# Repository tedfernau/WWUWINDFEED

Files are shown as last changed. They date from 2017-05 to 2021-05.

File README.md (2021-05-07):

# WWU WIND FEED

WWU Wind Feed was my 2017 senior project in electrical engineering. WWU Wind Feed is a microcontroller device that serves a web page with the current wind speed at Western Washington University's Lakewood Boathouse in Bellingham WA, USA.

The project was to develop an embedded system from concept to prototype, designing and building custom hardware and firmware.

https://user-images.githubusercontent.com/7742005/117382242-ee376c80-ae92-11eb-8817-17ec5c702b5a.mp4

The demonstration video is also on [youtube](https://www.youtube.com/watch?v=sEgjqADhZPg)

## Conceptual Design

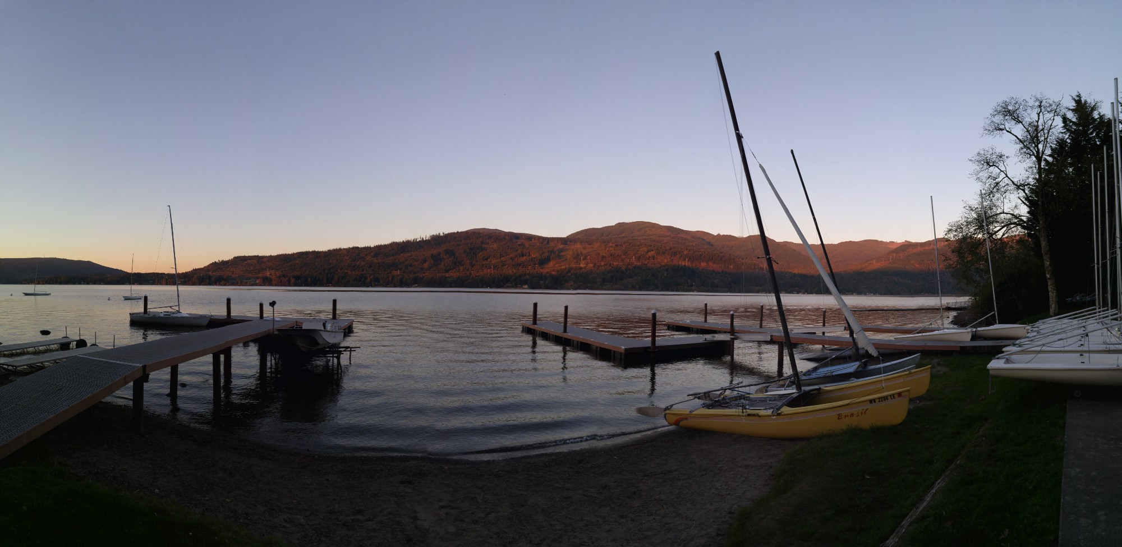
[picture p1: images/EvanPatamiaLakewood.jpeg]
Evan Patamia Lakewood photo
*Boathouse at WWU*

Western Washington University has a great boathouse on Lake Whatcom. Students rent sailboats, windsurf boards and various other watercraft and take classes and lessons. I learned to sail in a class at Lakewood, and later worked there teaching sailing lessons.

To have a good day of sailing you need wind. When you want to go sailing, you should check the wind conditions. A quick google search will give you decent wind data, but it is better to have localized data for the specific water you will be boating on. WWU Wind feed aims to provide this information. 

The ideal solution would provide all the data anyone needs to decide whether to visit Lakewood: wind on the water, and also temperature and weather conditions, a weather forecast, or maybe a picture, perhaps even boat or parking availability. The data would be made available as conveniently as possible to interested parties. This may be a social media post for subscribers(a great job for a Twitter bot) or a widget on the Lakewood webpage. This is a weather station and inventory system with serious web capability! Compromises were made... to provide only wind data and to serve a simple webpage.

More compromises. We sail on the middle of the lake, this is the wind we want to measure. This requires a buoy, solar panel, a battery, long range wireless communication to an internet gateway (cellular or perhaps LORA), weather proofing and permission for installing such a buoy. For achievability and cost savings, I decided the device will be at the boathouse, plugged into the wall, connected to the Lakewood WiFi.

Below I dumped documents for a technical audience to quickly evaluate this project followed by a brief conclusion. Feel free to reach out to me for more information.

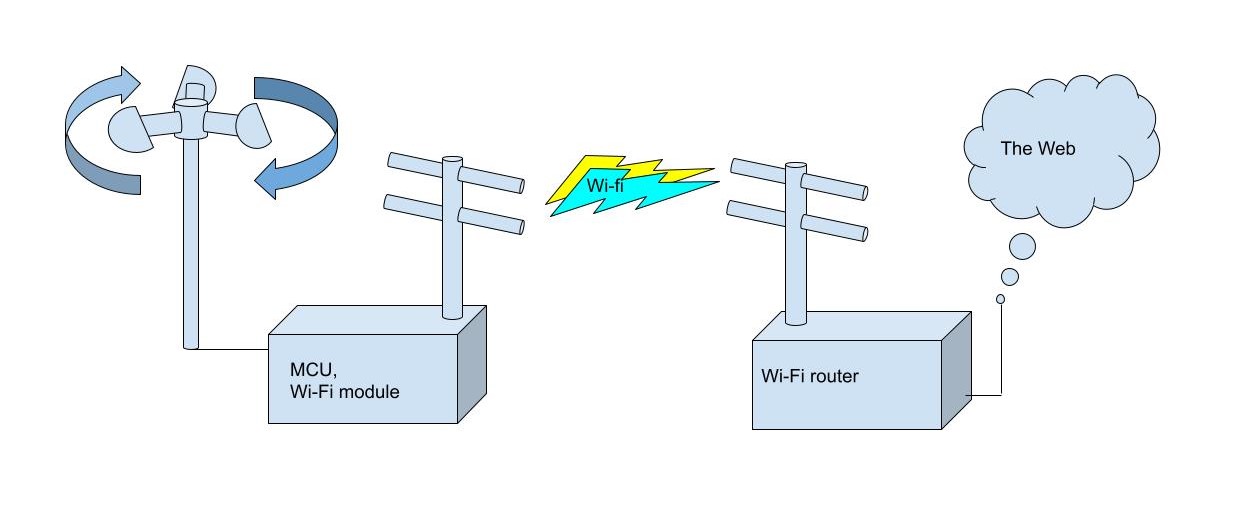
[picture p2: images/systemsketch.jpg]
System concept
*System Sketch*
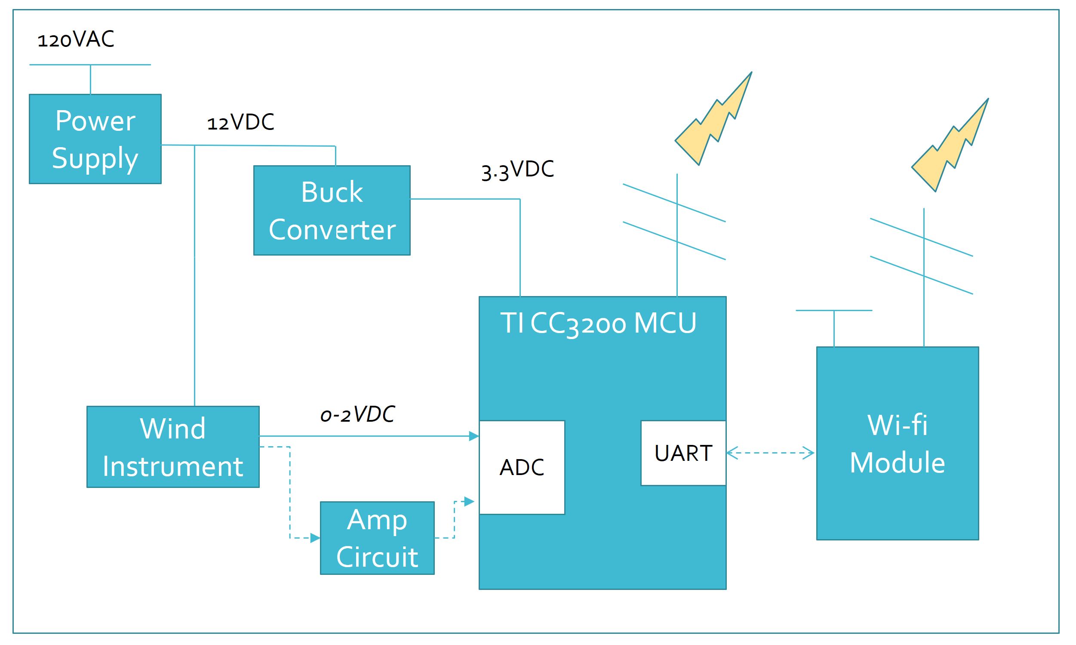
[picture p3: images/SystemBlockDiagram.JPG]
System Block Diagram
*System Block Diagram*

## [Hardware](https://github.com/tedfernau/WWUWINDFEED/tree/master/hardware)

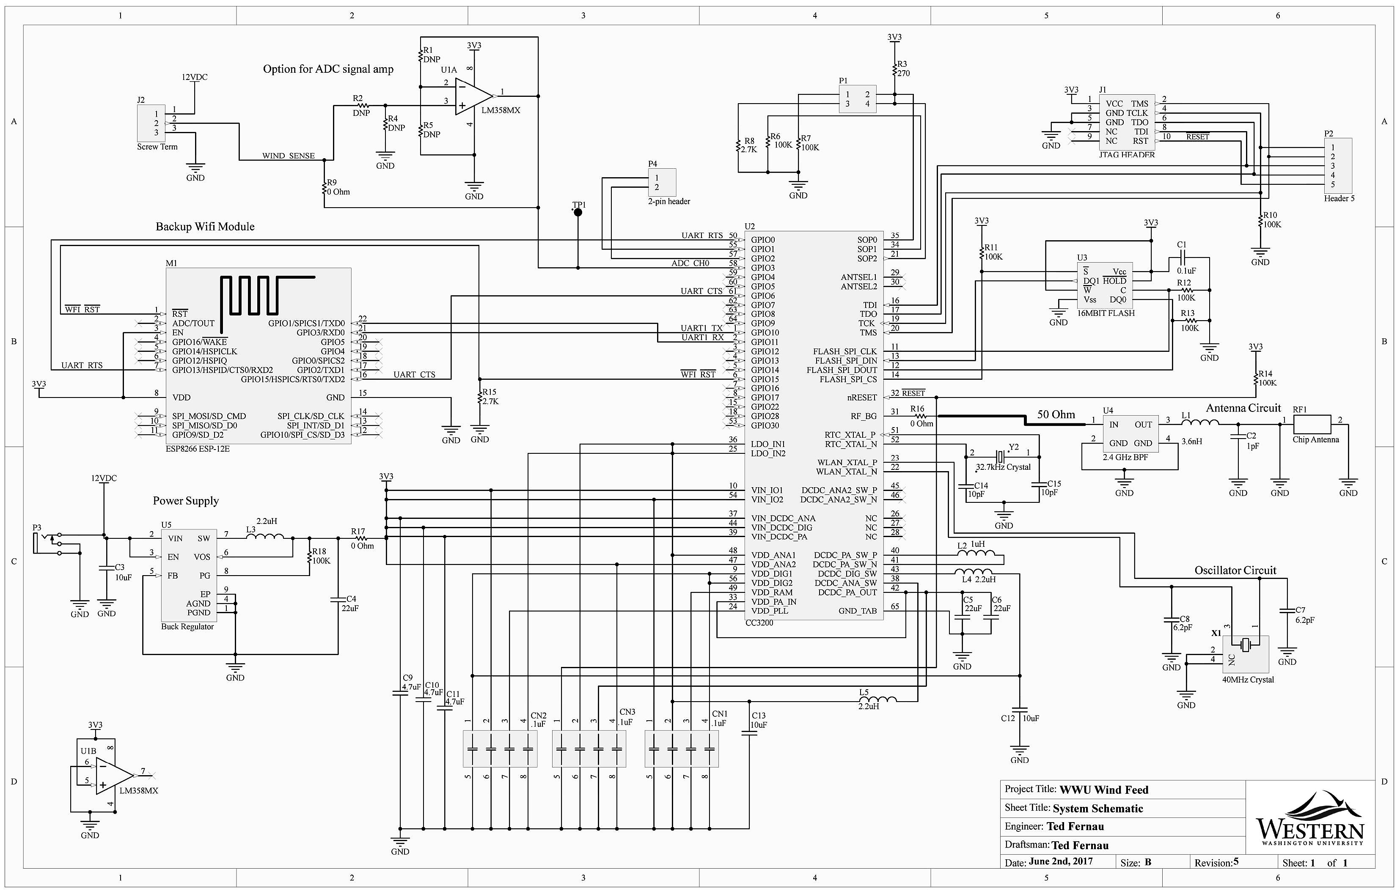
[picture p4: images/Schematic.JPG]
Schematic
*Schematic*
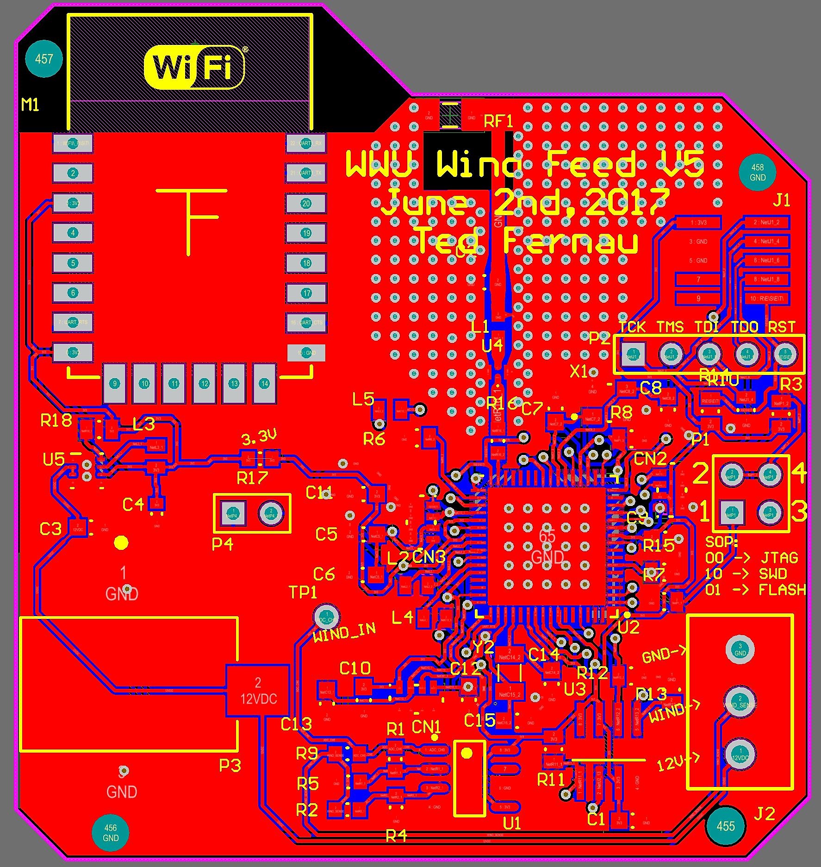
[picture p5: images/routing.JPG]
Composite Layout and Routing
*PCB Layout*
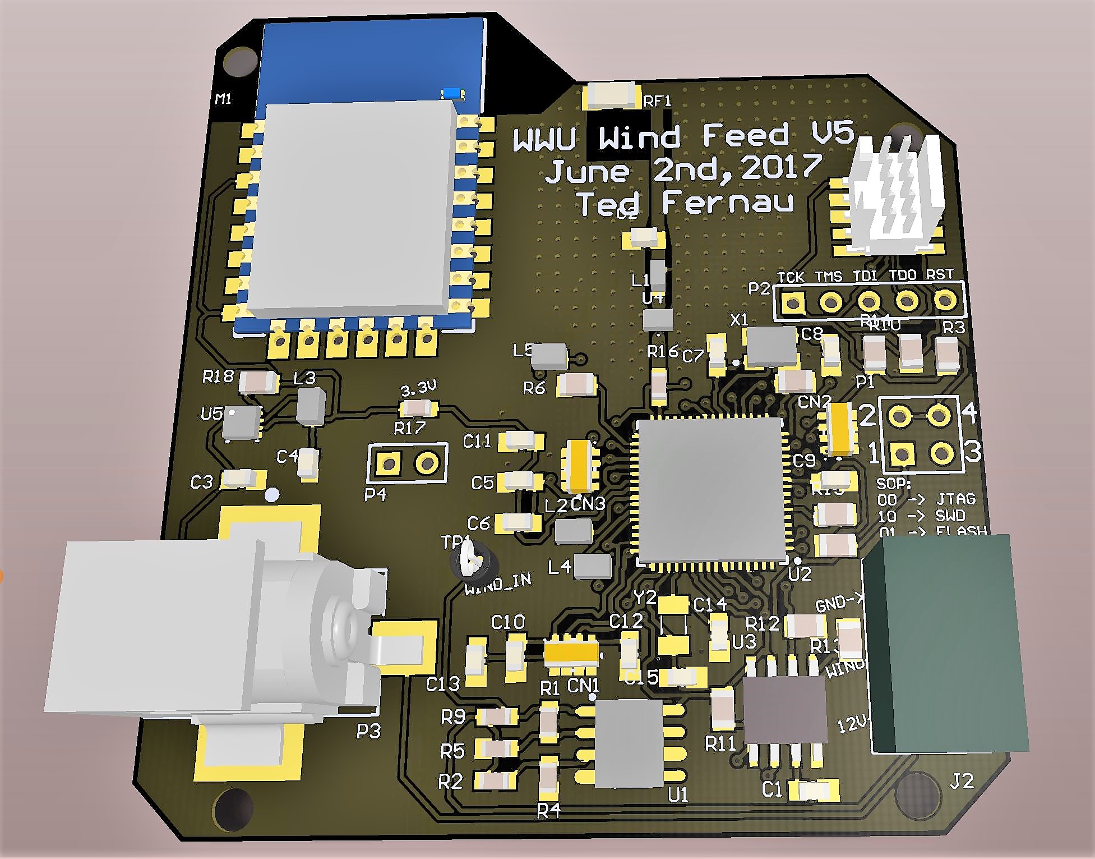
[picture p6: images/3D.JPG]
3D rendering
*Rendering of PCB*
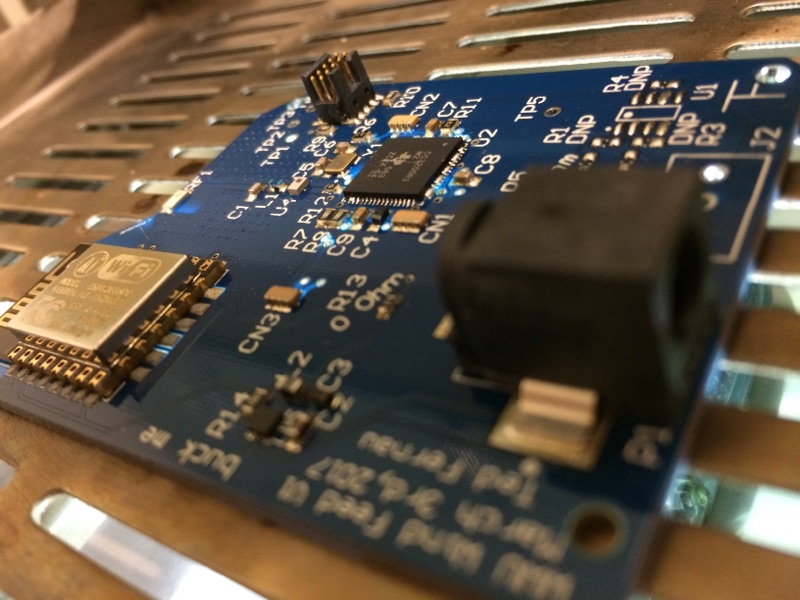
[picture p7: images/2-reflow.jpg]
Reflow
*PCB Assembly - Reflow*

## [Firmware](https://github.com/tedfernau/WWUWINDFEED/tree/master/firmware)

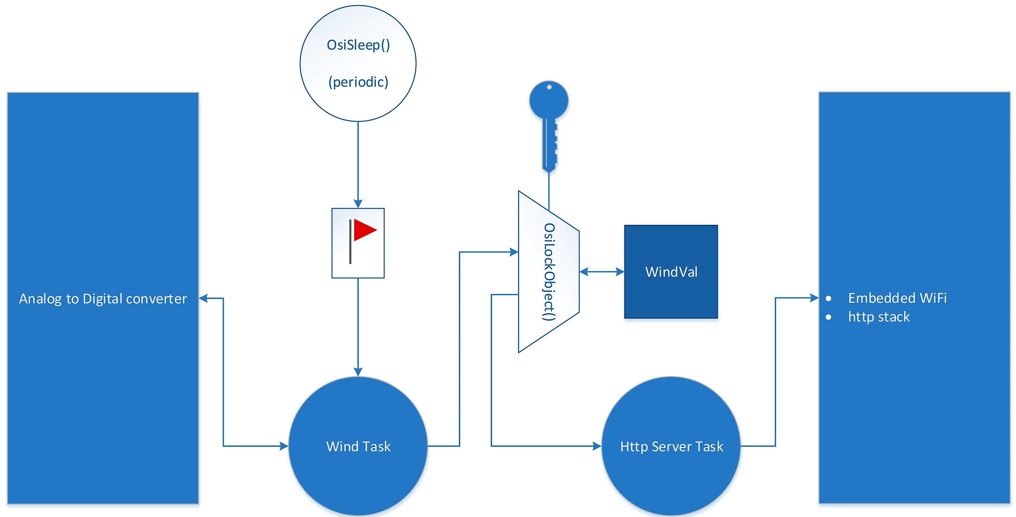
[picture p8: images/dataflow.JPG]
dataflow
*Dataflow Diagram*
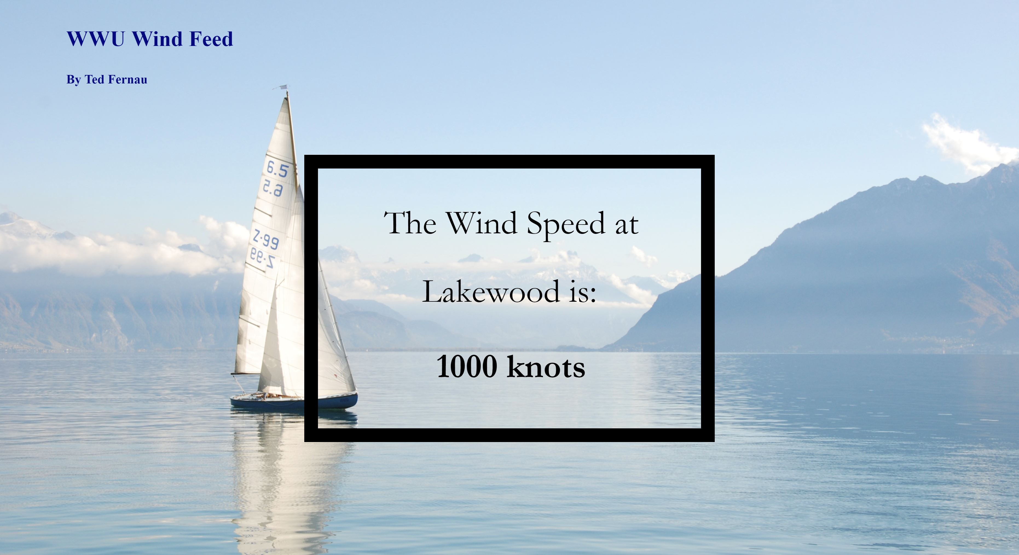
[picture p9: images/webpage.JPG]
webpage
*Webpage Design*

## Thoughts

This project was a great first dive into product design, mixed signal electronics design, PCB design, PCB assembly, debugging and rework, firmware development in C, and project management. The experience revealed deficits in my skills, knowledge, and personality. These revelations have been useful.

If I were going to pick this project up again, I would not make all the compromises I mentioned above. The device would run off of solar, and would not use WiFi for accessing the network. I am not sure a buoy is worth the hassle, but perhaps the device could be attached to a dock or piling and still give useful data(needs study). I would likely try to provide a picture of water conditions at least, and would look into providing the data more places on the web. 

Thank you for stopping by. Feel free to contact me, my info is on my github profile.

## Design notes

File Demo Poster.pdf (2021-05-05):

# WWU WIND FEED

# A custom IoT weather station. Designed to

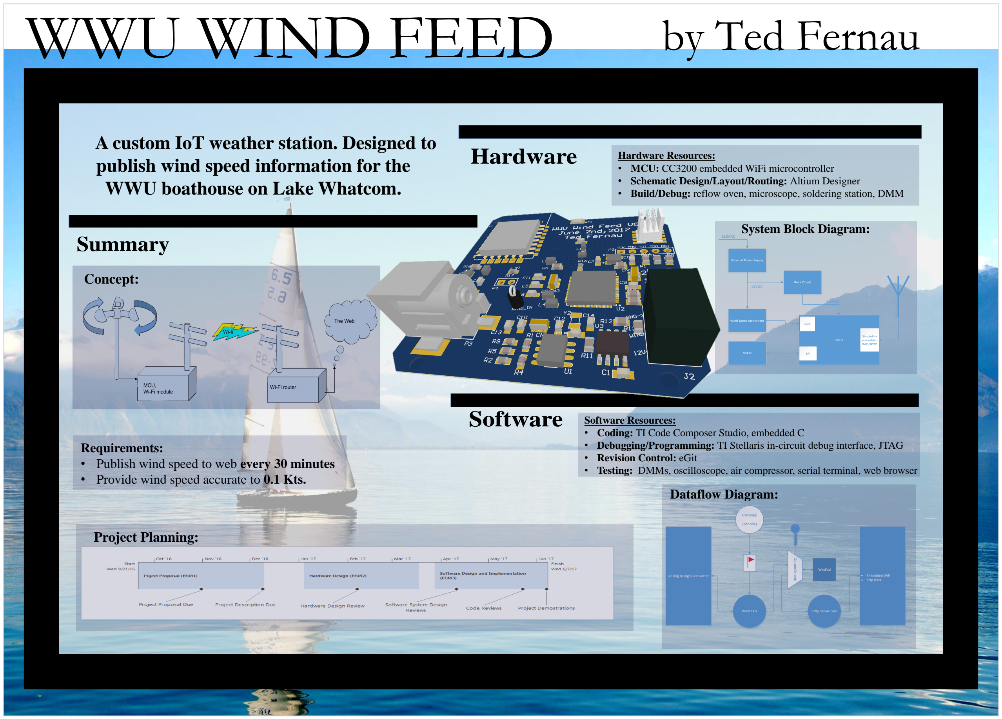
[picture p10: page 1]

# publish wind speed information for the

WWU boathouse on Lake Whatcom.

# Hardware Summary

### Requirements:

### - Publish wind speed to web every 30 minutes

- Provide wind speed accurate to 0.1 Kts.

## Project Planning:

# by Ted Fernau

External Power Supply

Wind Speed Instrument

Buck Circuit

SRAM

MCU

ADC

Simplelink
embedded
WiFi/HTTP

SPI

120VAC

12VDC

## 3.3VDC Concept:

Hardware Resources:
- MCU: CC3200 embedded WiFi microcontroller
- Schematic Design/Layout/Routing: Altium Designer
- Build/Debug: reflow oven, microscope, soldering station, DMM

Software Resources:
- Coding: TI Code Composer Studio, embedded C
- Debugging/Programming: TI Stellaris in-circuit debug interface, JTAG
- Revision Control: eGit
- Testing: DMMs, oscilloscope, air compressor, serial terminal, web browser

### Dataflow Diagram: System Block Diagram: Software

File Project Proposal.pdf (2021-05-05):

## EE 491 Senior Project Proposal WWU Wind Feed

### Ted Fernau

Summary

The WWU Wind Feed is a tool to deliver wind information to users of the WWU boathouse on Lake Whatcom. The system will collect wind speed (and possibly other) data and upload it to the Internet at regular intervals. The device utilizes an off the shelf marine anemometer, and does information processing and communication with an embedded microcontroller and a Wifi module. The system will be powered by the grid.

### 1 Detailed Description

The goal of this project is to provide wind speed data for the users of the WWU boathouse on Lake Whatcom. The wind conditions on the lake in front of the facility are unpredictable and are not accurately represented by the weather forecast for Bellingham. For this reason members of the WWU wind sport community frequently call Lakewood for a wind update. I propose a device to measure wind speed periodically and publish the data online for user consumption. Providing current wind conditions makes it easier for users to decide when to go boating. This device utilizes the fact that most WWU students and alumni have smart phones, and can access the web conveniently.

Wind speed is the focus of this project because this is vital information for those who participate in wind sports. Wind sports equipment represents the bulk of the available rentals at the WWU boathouse. Other local information is important for the users of the WWU boathouse such as air temperature, water temperature, hours of operation, wind direction, etc. This other data is reported by the Bellingham weather forecast.

The goal described above leads to the following product features, listed in order of priority:

Make current wind speed available to WWU boaters. This is the key feature of the project. This feature is necessary due to the reasons described above, that wind speed is not accurately represented by weather reports, wind speed is the most important information for those who enjoy wind sports, and wind sports represent most of the resources available to the WWU community.

Provide historical wind data to indicate trends. Besides the current wind speed, an important determinant of sailing conditions is the wind speed trend. This allows users to determine whether the wind speed is increasing or decreasing, and thus better choose when to sail. Ideally, publishing the information would include a graphical output, providing context for the current wind speed.

Publish wind data in the optimal format for user consumption. Some formats are more convenient for users than others. The easiest way to accomplish the goal of making information available to all is to publish data on a web page. Users can be assumed to have internet access. Mobile internet access is also ubiquitous and represents an important and growing proportion of information services. In addition to a simple web page, social media may be an efficient way to deliver to those interested. It has been proposed that using the Lakewood Twitter feed may increase visibility.

Provide other relevant data besides such as wind direction, temperature, and barometric pressure. There is other information that could be useful to users. It would be ideal to publish as much relevant data as possible, in order to provide the most benefit to the most people. Some possible additions are wind direction, temperature, and barometric pressure data.

### 2 Constraints and Standards

There is limited space available at the Lakewood facility, and still less space that is exposed to wind conditions similar to those at the middle of the lake. The space occupied must be suitable to accomplishing the goal of the project, while being suitable to Lakewood users and management.

In order to meet the goal, and provide for the features listed above and the benefits below, the product must be reliable. The device must withstand outdoor conditions with little or no maintenance over the lifecycle.

The cost must be on par with other low end solutions on the market, which is roughly under $200. This is a fixed device that would be installed for long term use. This is also a custom solution, which allows for some deviation in price for the purpose of reliability and key features. The budget for developing a prototype is subject to the limitations of the personal finance of the creator.

The product must operate without affecting boathouse operations. This is not a project Lakewood management is seeking out, thus there is little accommodation for any imposition on the facility and operations, thus product must be retrofitted to the boathouse as it presently exists. This means the product must communicate with the existing network using standard protocols.

The product must be designed, with a working prototype, by early June. This limits the likelihood of added features. The features will be developed in order of importance. There will be no added features until the initial goal is satisfied, and it is cost and time effective to add them.

### 3 Benefits

This product is meant to demonstrate a possible application for the 'Internet of Things' (IoT), and represents a template for a broad range of possible products. In the process of developing this solution I will become familiar with the relevant issues for IoT design. The product is also an exploration of the so-called information economy. One of the largest roles for technology in today’s world is to provide relevant information to economic participants in order to reduce transaction costs, thus leading to more efficient market outcomes. I see the end point of this progression as a more informed society that is better able to understand and react to our changing world.

This product benefits the user by providing the necessary information to utilize a small segment of the WWU recreational resources. If the solution is properly implemented, it will make the Lakewood Boathouse a more efficient organization by reducing the cost associated with providing redundant information.

Most of the solutions that currently exist come in two forms: boat mounted instrument systems that provide wind data for a vessel, and remote weather stations for home or commercial use. The products for boats differ from my design since they are not generally broadcast oriented, instead displaying information to the vessel crew to be used in the moment.

Remote weather stations are more similar to this design, since they monitor conditions at a remote location and display at a base station. These products come with various features, some that are accessible with a smart phone or tablet. These are largely integrated systems that vary largely in features and cost. My solution is a scaled back version of a remote weather station, with the focus on making the data ubiquitous by putting in on the web. Another difference is this product is meant to represent many one off designs that could be fitted to any application.

The broader benefits of this product is reduced cost of Lakewood usage for the users, WWU, and society. The cost of usage is saving a phone call or a trip out to the Boathouse. The benefit to Lakewood management is a decrease in inquiries about wind conditions, thus freeing resources for more efficient operation. Society benefits from the decreased energy consumption from fewer wasted trips.

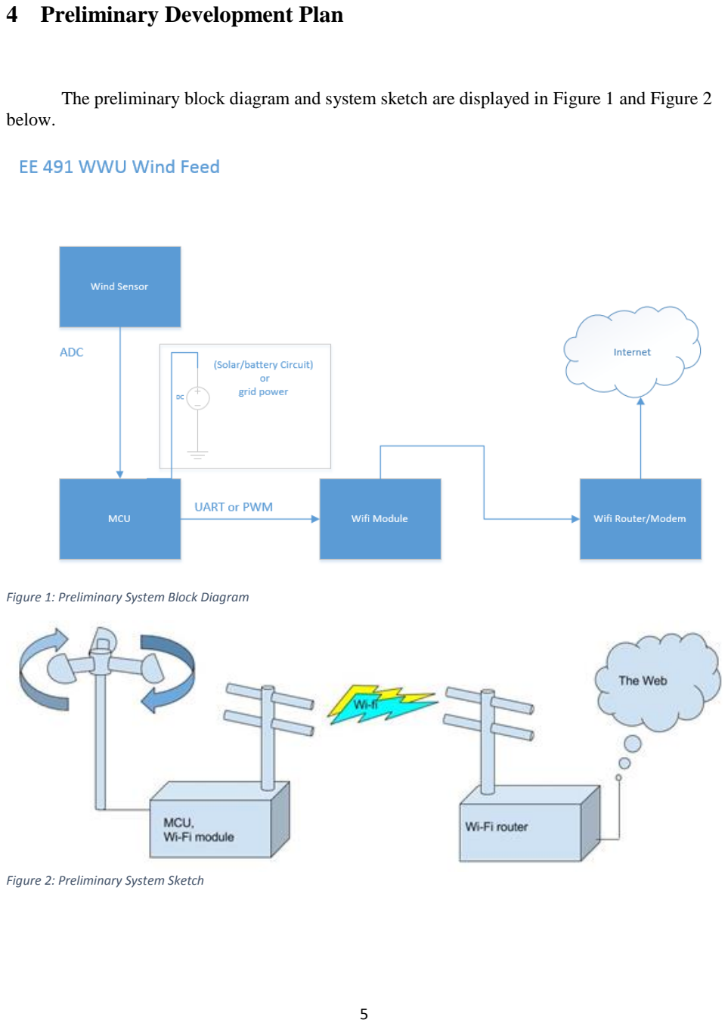
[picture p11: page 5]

### 4 Preliminary Development Plan

The preliminary block diagram and system sketch are displayed in Figure 1 and Figure 2 below.

Figure 1: Preliminary System Block Diagram

Figure 2: Preliminary System Sketch

In order to design and implement this product, I will first need to answer a couple initial questions: Where is the optimal location to accurately monitor wind speed on the Lakewood campus? In order to answer these questions, I will consult with Lakewood management and
WWU EE faculty for relevant constraints and guidance.

Once I have decided these details, the next step is to source parts that will be optimum for a prototype. I plan on purchasing the anemometer early to build a rough prototype of the sensor circuit, and to optimize the instrument location. This sourcing of parts will be done online, or possibly at local marine supply stores.

I will be designing an IC for the prototyping and implementation, so I will next decide which micro controller will be optimum for my design, as well as necessary peripherals including the Wi-Fi module. This will be done by finding the relevant constraints, and searching online for components that achieve the maximum required performance, without extra cost or complexity.

Once the hardware design is complete, I will move to software design and implementation. For this I will utilize the resources that exist in the WWU EE labs.

Once the design is complete, I will move to implementing a prototype using the WWU EE lab resources as much as possible.

Depending on the quality of the prototype, I will work to implement a version of the system at the Boathouse. I would like to have a prototype to demonstrate in the lab, as well as the stream of actual weather data from the lake.

### 5 Bibliography

Possible parts:

Wind Sensor:

http://www.ebay.com/itm/Climatronics-Wind-Speed-Sensor-100075-/331589368095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

http://www.ebay.com/itm/Wind-Speed-Sensor-Anemometer-Three-Cups-Aluminium-Alloyed-Voltage-Output-0-5V-
/322206596553?hash=item4b05027dc9:g:FCsAAOSweXhXmFCu (http://www.ebay.com/itm/Wind-Speed-Sensor-Anemometer-Three-Cups-Aluminium-Alloyed-Voltage-Output-0-5V-/322206596553)

https://www.adafruit.com/product/1733

Wi-Fi Module:

http://gridconnect.com/tiny-wifi-module-802-11-b-g-n-industrial-grade-temperature.html

Relevant Academic Papers:

M. Popa and C. Iapa, "Embedded weather station with remote wireless control," Telecommunications Forum (TELFOR), 2011 19th, Belgrade, 2011, pp. 297-300.

URL: http://ieeexplore.ieee.org/stamp/stamp.jsp?tp=&arnumber=6143549&isnumber=6143488

A. Shaout, Yulong Li, M. Zhou and S. Awad, "Low cost embedded weather station with intelligent system," Computer Engineering Conference (ICENCO), 2014 10th International, Giza, 2014, pp. 100-106.

URL: http://ieeexplore.ieee.org/stamp/stamp.jsp?tp=&arnumber=7050439&isnumber=7050418

B. C. Mishra, A. S. Panda, N. K. Rout and S. K. Mohapatra, "A Novel Efficient Design of Intelligent Street Lighting Monitoring System Using ZigBee Network of Devices and Sensors on Embedded Internet Technology," 2015 International Conference on Information Technology (ICIT), Bhubaneswar, 2015, pp. 200-205.

URL: http://ieeexplore.ieee.org/stamp/stamp.jsp?tp=&arnumber=7437615&isnumber=7437547

Xiaoneng Gao and Pengtong Fan, "Internet access technology based on the embedded devices," Multimedia Technology (ICMT), 2011 International Conference on, Hangzhou, 2011, pp. 391-394.
URL: http://ieeexplore.ieee.org/stamp/stamp.jsp?tp=&arnumber=6001932&isnumber=6001647

Relevant Datasheets:

http://www.climatronics.com/pdf_pn/Wind_Speed_Direction/100075,100076,101994.pdf

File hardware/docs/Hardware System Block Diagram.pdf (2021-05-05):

### 120VAC

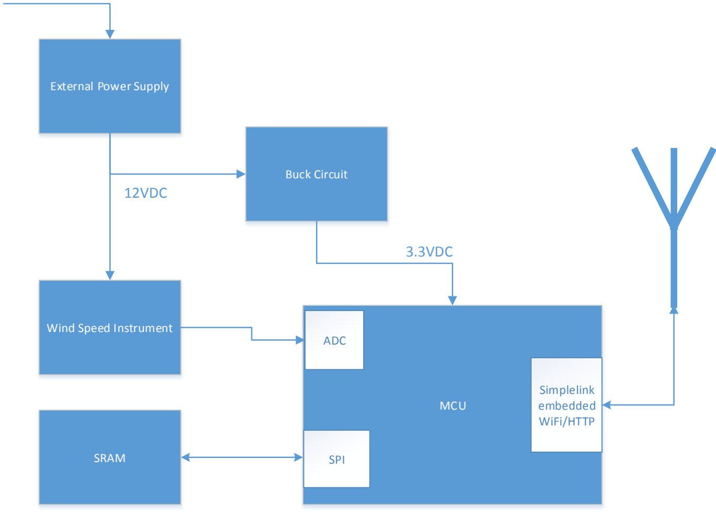
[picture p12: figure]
External Power Supply; Wind Speed Instrument; Buck Circuit; SRAM; MCU; ADC; Simplelink embedded WiFi/HTTP; SPI; 12VDC; 3.3VDC

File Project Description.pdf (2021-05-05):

## EE 491 Senior Project Description WWU Wind Feed

## Ted Fernau

### Summary

The WWU Wind Feed is a tool to deliver wind information to users of the WWU boathouse on Lake Whatcom. The system will collect wind speed (and possibly other) data and upload it to the Internet at regular intervals. The device utilizes an off the shelf marine anemometer, and does information processing and communication with an embedded microcontroller and a Wi-Fi module. The system will be powered by the grid.

## 1 Project Requirements

- The device must publish the current wind speed for Lake Whatcom’s third basin on a webpage that is easily available for PC and smartphone access.
- The wind feed website will be hosted on the device.
- Online information must be updated every 30 minutes.
- Published wind speed information must be accurate to within 1 knot with a resolution of 0.5 knots.
- The device must operate to specifications in wind speeds from 1 knot to 60 knots.
- The device must operate in temperatures from -18 to 40 degrees Celsius.
- All outdoor components, the wind speed instrument and cable, must withstand year round weather conditions.
- The device must cost less than 200USD to implement from the supply side.
- The device must interface with the local internet router via Wi-Fi protocols IEEE 802.11 b/g/n, and must be able to meet security constraints for network access.
- The device must be powered by a standard 120VAC outlet and draw less than a typical Wi-Fi router, about 50 mA (for 6Watts).
- The device must be the roughly the size of a standard internet router/modem, roughly 4 inches by 6 inches by 1 inch.

## 2 System Design Formulation and Specifications

The product collects weather data via an anemometer instrument. The instrument is a transducer from wind speed to a linear voltage output from 0.4 to 2V DC. The anemometer requires a 12VDC power supply. This signal is sampled by the ADC of the microcontroller, and the wind speed is calculated based on the input signal. Wind speed data is passed to the Wi-Fi module using UART. The Wi-Fi module has integrated TCP/IP protocols to communicate with the local Wi-Fi network. The device accesses the network in order to serve the webpage which displays current wind conditions. This website is hosted by the device.

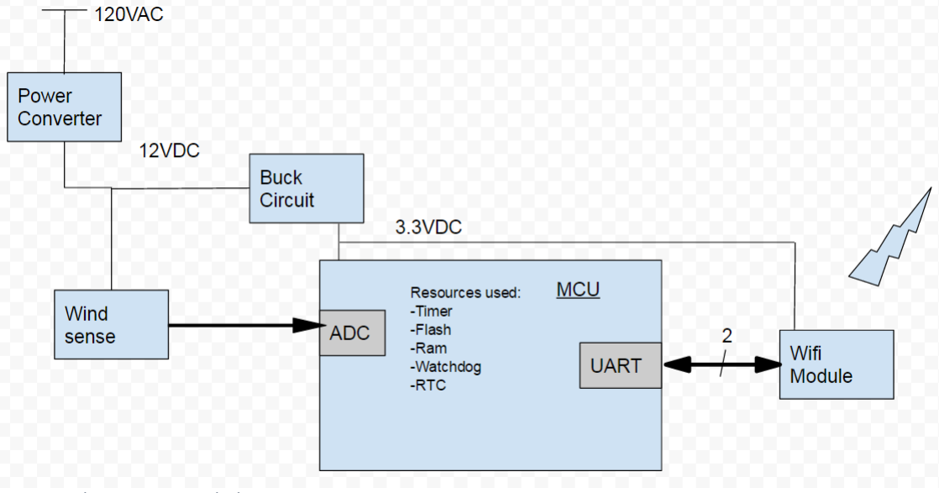
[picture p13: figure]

Figure 1: Preliminary System Block Diagram

a. Hardware

Microcontroller Specs: For this project I require at least 38kB ROM, 0.1 kB RAM, an ADC range of 193 levels, so 9 bit resolution. The project requires an MCU with UART capabilities. The MCU listed in appendix A meets these requirements, but has some superfluous features: 64kB ROM, 16kB RAM, UART, 16 and 24 bit ADCs.

Resources: The MCU resources I will use for this project are the ADC to sample the wind speed instruments voltage output, UART for communication between the MCU and the Wi-Fi module, a timer for the periodic updating of wind information, the watchdog timer, since the device will run continuously, to reset the system in the case of an error, and the RTC if I implement a timestamp publication.

Other components: the Wi-Fi Module must operate at the same supply voltage as the MCU, in this case 3.3V. The Wi-Fi module must also either be a Surface mount component or have a form factor small enough to fit in the form described above. The Wi-Fi module must communicate using the IEEE 802.11 b/g/n protocol for compatibility with the in-place Wi-Fi system. The wind speed transducer must be weatherproof for continued outdoor operation, and must produce a voltage signal between 0 and 3.3V for use with the MCU ADC. Ideally the transducer would be self-powered, but the self-powered instruments are proprietary and expensive. The sensors I considered had a minimum supply voltage of 12VDC, so I will supply 12V to the sensor.

Power Supply Specs: The 120VAC to 12VDC must supply 500mA. The system is estimated to draw about 80mA from the 120 to 12 converter, I am using a very conservative margin of error. The 12VDC to 3.3VDC must supply a minimum of 200mA, but again I will use 500mA to ensure performance.

PCB size Requirements: The device as a whole must resemble a Wi-Fi router in form. This means the device must be roughly 4 inches wide by 6 inches long by 1 inch tall. This leaves room for a 3.5 inch by 5.5 inch PCB if necessary. I used these dimensions in my parts list, but I will attempt to use a smaller PCB to save cost.

b. Software

Programming languages: I will program the board in Kinetis Design Studio, which uses
C. For the webpage I will use HTML.

Real time kernel Type: uC/OS by Micrium is the kernel I have experience with, so I will most likely use it for software multitasking.

Major algorithms: The Wi-Fi module has integrated TCP/IP, I will be coding using HTTP to serve the webpage.

## 3 Development Plan

a. Prioritized list of device features Primary
1. Make current wind speed available to WWU boaters.
Secondary
2. Provide timestamp with wind speed, display historical wind data.
3. Publish wind data in the optimal format for user consumption (i.e. | social via social media).

Table 1: Prioritized list of features

b. Description of project development tasks and sequence
Winter Quarter 2017 - Hardware Design
Week | Dates | Tasks
1 | Jan 4-6 | Verify hardware block diagram as optimum design
2 | Jan 9-13 | Order parts essential to prototyping such as the wind sensor, simulate circuitry to verify design integrity.
3 | Jan 16-20 | Begin characterizing wind sensor output, Learn Altium tool
4 | Jan 23-27 | Buy and test as many components as possible.
5 | Jan 30-Feb 3 | Develop prototype of major device functions for onsite testing
6 | Feb 6-10 | Finalize circuit layout, produce complete schematic of system Hardware Design Reviews Feb 7th
7 | Feb 13-17 | Review schematic for PCB fabrication
8 | Feb 20-24 | Order PCB
9 | Feb 27-March 3 | Breadboard whatever possible while waiting for PCB
10 | March 6-10 | Assemble hardware for testing.
11 | March 13-17 | Catch up
Spring Quarter 2017 - Software Design
Week | Dates | Tasks
1 | March 28-31 | Formulate top level block diagram
2 | April 3-7 | Research web servers, TCP/IP, static websites, possible publishing media PCB Fully Assembled and Tested April 4th
3 | April 10-14 | Formulate detailed block diagrams of modules Software System Design Reviews April 11th
4 | April 17-21 | Develop basic prototype for testing
5 | April 24-28 | Catch up
6 | May 1-5 | Catch up
7 | May 8-12 | Implementation
8 | May 15-19 | Implementation
9 | May 22-26 | Implementation and prepare presentation Code Reviews May 23
10 | May 29- June 2 | Catch up
11 | June 5-9 | Project Demonstrations June 7th (subject to changes)

Table 2: Project development plan c. Description of development hardware and software including source

Software: I will be using Kinetis Design Studio to program the MCU, Altium for PCB layout, Multisim for circuit simulation. I will utilize online weather forecasts in order to verify the accuracy of the device.

Hardware: I will need to find a wind speed meter to fine tune my accuracy and to verify the required resolution. I will utilize oscilloscopes, power supplies, multimeters, and fabrication supplies to build and test hardware and software systems. For prototyping, I will use as many components from the EE stock room as possible to avoid lead times and cost.

d. Prototype description

The prototype demonstration will occur in the EE labs. I will have a wind speed instrument set up with the online publishing occurring much faster than otherwise specified, likely every 30 seconds or so. A person will move the wind speed sensor, perhaps by blowing/a fan/ hand manipulation and watch as the webpage updates. Ideally I would have the final device in place at the boathouse for a real world demonstration, but I do not want to pay for two prototypes unless necessary.

## 4 User Interface Requirements

The user interface for this project takes the form of a web page. This web page should be viewable by users on a PC or smart phone. The UI is very simple since it only publishes data. There is no user control, only observation.

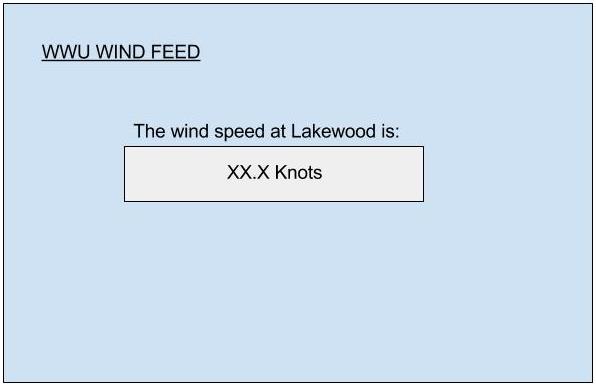
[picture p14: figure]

Figure 2: Sketch of website user interface

## Appendix A – Preliminary Parts List

Part number | Quantity | Description | Cost(USD) | Lead time | Current consumption (mA)
Power
dissipation
(W)

URL

120VAC to 12VDC converter
TOL-09442 | 1 | Wall Adapter Power
Supply - 12VDC
600mA
5.95 | 1-2 weeks | 600mA | Assume
| | | 85% efficiency

https://www.sparkfun.com/products/9 442

Supplied by 120VAC to 12VDC converter
1733 | 1 | Anemometer Wind
Speed Sensor
w/Analog Voltage
Output
44.95 each | 1-2 weeks | 4-20 | 0.240 | https://www.adafruit.com/product/173
| | | | 3

### 12 to 3.3VDC converter

TPS62172DSG R | 1 | Buck Switching Regulator IC Positive Fixed 3.3V 1 Output 500mA 8-WFDFN Exposed Pad | 1.56 | 1-2 weeks | 526 | 6.312 | http://www.digikey.com/product-detail/en/texas-instruments/TPS62172DSGR/296-39449-1-ND/5143397
PJ-035-SMT-TR | 1 | DC barrel Jack | 1.34 | 1-2 weeks | N/A | N/A | http://www.digikey.com/product-detail/en/cui-inc/PJ-035-SMT-TR/CP-035PJCT-ND/1530992-ltTikw66e-BR-Y4oCKYaRoCikTw_wcB
80-T322C106K15 AT | 1 | Tantalum Capacitors -Solid Leaded 15V 10uF 10% | 1.96 | 1-2 weeks | N/A | 0.1 | http://www.mouser.com/ProductDetail/Kemet/T322C106K015AT/?qs=sGA EpiMZZMsh%252b1woXyUXj2MEb xGkEkhEwwHS%2fNM7xfA%3d
TLCU226M00 6XTA | 1 | Tantalum Capacitors - Solid SMD 6.3volts 22uF 20% | 2.81 | 1-2 weeks | 54 (@100kHz) | 0.178 | http://www.mouser.com/ProductDetail/AVX/TLCU226M006XTA/?qs=sG AEpiMZZMsh%252b1woXyUXj2BG 3d9BWqHTUCbLPZ3%2fYBY%3d
TFM201610A LM-2R2MTAA | 1 | Fixed Inductors 2.2uH 146mohms 2.1A Thin Film Metal | 0.69 | 1-2 weeks | 2100 | 6.9 | http://www.mouser.com/ProductDetail/TDK/TFM201610ALM-2R2MTAA/?qs=sGAEpiMZZMukHu %252bjC5l7YXWyGFGQPUf1VJZQ eiZdbQI%3d
ESR10EZPJ1 04 | 1 | Thick Film Resistors - SMD 0805 100Kohm 5% Anti Surge AEC-Q200 | 0.10 | 1-2 weeks | N/A | N/A | http://www.mouser.com/ProductDetail/ROHM-Semiconductor/ESR10EZPJ104/?qs=s GAEpiMZZMtlubZbdhIBIGrVcSH3v ih4Eh1TPh5CImY%3d

Supplied by 12 to 3.3VDC converter
MOD-WIFI-ESP8266-DEV (or CC3100MOD) | 1 | Wi-Fi / 802.11 Development Tools WIFI MODULE ESP8266 DEV BOARD | 6.91 | 3 weeks | 170 | 0.561 | http://www.mouser.com/search/ProductDetail.aspx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
MKM14Z64A CHH5 | 1 | ARM Microcontrollers - MCU Kinetis M 32-bit MCU, ARM Cortex-M0+ core, 64KB Flash, 50MHz, MAPBGA 44 | 3.12 | 8 weeks | 11.5 run mode, with peripherals | 0.038 | http://www.mouser.com/ProductDetail/NXP-Freescale/MKM14Z64ACHH5/?qs=d Tl%2FGK1lAHKE9y6dPqmtiQ%3D %3D
Two layer PCB Prototyping service | 1 | Prototype PCB,FR4 substrate,ENIG finish, 1.6mm thick | (5 per sq.in. set of 3) For 5.5x3.5in., 96.25 | 12 days | N/A | N/A | http://docs.oshpark.com/services/

## Appendix B – Cost Breakdown

The total cost of all components listed is: $225.64. My time is worth a wage of $100, 40 hours per week for 22 weeks: $88,000. There is a cost involved with using the development tools on campus. These will be ignored for now. The preliminary total cost: $88,225.64.

## Appendix C – Power Budget Calculations

To compute overall power consumption, I will begin at the dissipation of peripherals and work back upstream. I will assume an 85% efficiency of all switching voltage regulators. In order to calculate power consumption of components, as listed in Appendix A, I will use the following formulas: P = I²R = IV.

Power supplied by the 12 to 3.3VDC converter is: 0.599 W

Power supplied to the 12 to 3.3VDC converter is: 0.599 / 0.85 = 0.705 W

Power supplied by the 120VAC to 12VDC converter is: 0.705 + 0.24 = 0.945 W

Power supplied to the 120VAC to 12VDC converter is: 0.945 / 0.85 = 1.11W

Total power consumption = 1.11W

Total current at outlet = 1.11W / 120VAC = 9.26 mA

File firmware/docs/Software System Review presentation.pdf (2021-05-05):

# WWU WIND FEED

Software System Review

# Summary

The WWU Wind Feed is a tool to deliver wind information to users of the WWU boathouse on Lake Whatcom.
The system will collect wind speed data and upload it to the Internet at regular intervals.

# Tools

Coding: TI Code Composer Studio

Debugging/Programming: TI Stellaris in-circuit debug interface , JTAG

Revision Control: eGit

Testing: DMMs, oscilloscope, air compressor, serial terminal, web browser.

# MCU Resources

CC3200

Bus Frequency: 80 MHz

RAM: need 2kB, have 256kB

ROM: need 38kB, have 64kB

On-chip resources: ADC, timer, periodic interrupt, ADC interrupt, On chip WiFi protocol stack.

# Kernel and Tasks/ISRs

- TI RTOS
Task | description | priority | Execution period | Execution time | Execution period with ISR | Cpu load
Server task | Serve webpage | 2 | sporatic | depends | NA | ~75(?)
Wind task | Read ADC, calculate wind data | 1 | 30 min | <10 ms | <10ms | 0
Startup task | Startup code, initialization | NA | NA | <20 ms | NA | NA

# Modules and Library

Module | Tasks | Public Functions | Public Data | Prewritten? | Licensing
main.c | Startup task, wind task, server task | Getwind() | WindVal | no | NA
adc.c | NA | NA | NA | yes | TI open
simplelink.c | NA | NA | NA | yes | TI
network_common.c | NA | NA | NA | yes | TI
smartconfig.c | NA | NA | NA | yes | TI
systick.c | NA | NA | NA | yes | TI
interrupt.c | NA | NA | NA | yes | TI

# Inter-Task

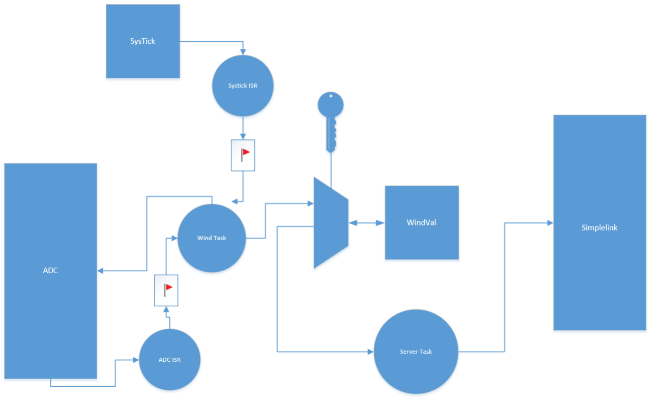
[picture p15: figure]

Communications Dataflow. State diagram

# Testing and Verification

- Verify periodic updating of wind data with web browser
- Compare published wind speed with forecasts/estimates
- Verify performance at high wind speeds with air compressor.
- enclose device and test reliability in outdoor environment
- Measure device power consumption

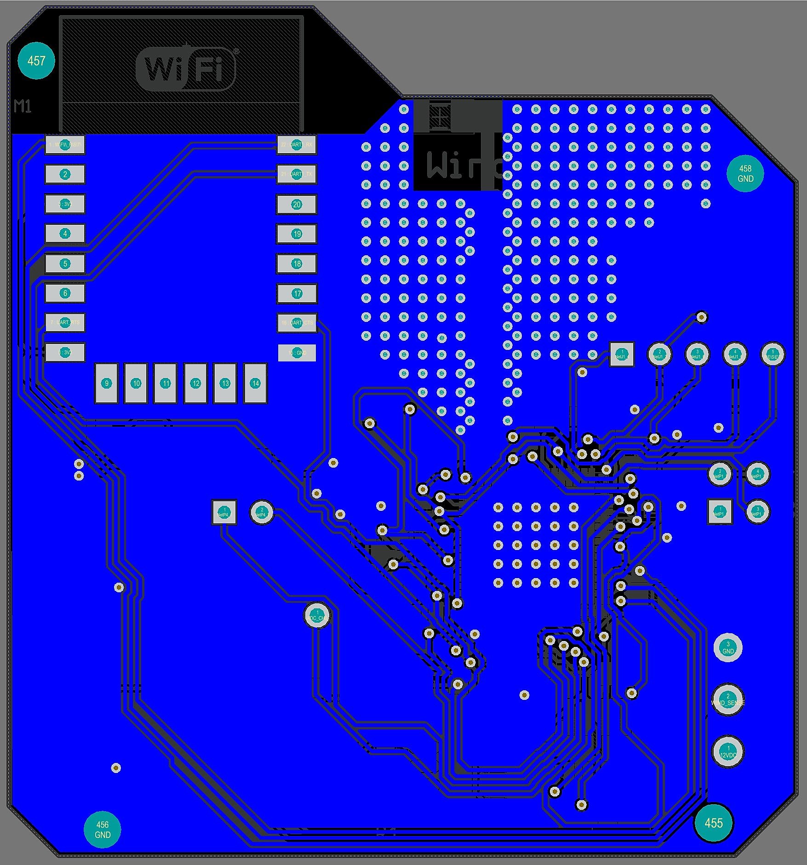
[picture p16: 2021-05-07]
images/BottomLayer.JPG

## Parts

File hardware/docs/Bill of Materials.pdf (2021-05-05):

Bill of Materials For WWU Wind Feed

# Component list

Report Date: | 3/17/2017 | 2:04:20 PM
Print Date: | 08-Jun-17 | 5:15:25 PM

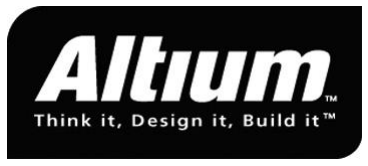
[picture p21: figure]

Type | Description | Designator | Part number | Price | Cost | Quantity
MCU
| CC3200 MCU | U2 | CC3200R1M2RGC | $12.16 | $12.16 | 1
| 10 pin JTAG header | J1 | FTSH-105-01-L-DV-K-TR | $3.25 | $3.25 | 1
| 32.768kHz crystal | Y2 | ABS07-32.768KHZ-T | $0.61 | $0.61 | 1
Memory
| 128Mb serial flash | U3 | MX25L12835FM2I-10G | $2.21 | $2.21 | 1
Sensor
| anemometer, 0-2VDC output | N/A | 1733 | $44.95 | $44.95 | 1
| general purpose op-amp | U1A | LM358DT | $0.39 | $0.00 | 0
| 3 point screw terminal block | J2 | OSTTE030104 | $0.50 | $0.50 | 1
Power
| wall adapter, 12VDC | N/A | ALD08-12FU | $5.95 | $5.95 | 1
| barrel jack connector | P3 | RASM722X | $1.39 | $1.39 | 1
| buck regulator IC, 12 to 3.3VDC | U5 | TPS62172DSGR | $1.56 | $1.56 | 1

RF
| 2.4 GHz band pass filter | U4 | DEA202450BT-1294C1-H | $0.51 | $0.51 | 1
| 2.4GHz chip antenna | RF1 | AH316M245001-T | $1.41 | $1.41 | 1
| 40MHz crystal | X1 | CX3225SB40000D0FFFCC | $0.80 | $0.80 | 1

Backup RF
| RF transceiver module | M1 | ESP8266 - 12E | $3.95 | $0.00 | 0
Debug
| test point | TP1 | 5001 | $0.37 | $0.37 | 1
| headers | P1, P2 | NA | $0.00 | $0.00 | 2
Generic | | Value
| capacitors
0.1uF | C1 | CC0603ZRY5V9BB104 | $0.10 | $0.10 | 1
1pF | C2 | 251R14S1R0BV4T | $0.24 | $0.24 | 1
10pF | C14, C15 | 251R14S100JV4T | $0.32 | $0.64 | 2
10uF | C3,C12,C13 | GRM188R61C106KAALD | $0.34 | $1.02 | 3
22uF | C4,C5, C6 | GRM188R60J226MEA0D | $0.23 | $0.69 | 3
6.2pF | C7,C8 | CL10C6R2DB8NNNC | $0.10 | $0.20 | 2
4.7uF | C9,C10,C11 | CL10B475KQ8NQNC | $0.10 | $0.30 | 3

cap.array, 4 each
0.1uF | CN1,CN2,CN3 | W3A4YC104KAT2A | $0.45 | $1.35 | 3

inductors
3.6nH | L1 | LQW18AN3N6D00D | $0.17 | $0.17 | 1
2.2uH | L3,L4,L5 | MLZ2012M2R2HT000 | $0.15 | $0.45 | 3
1uH | L2 | MLZ2012M | $0.15 | $0.15 | 1
resistors
DNP | R1, R2, R3, R4 | NA | $0.00 | $0.00 | 4
0 Ohm | R5,R13,R14 | RC0603JR-070RL | $0.10 | $0.30 | 3
270 Ohm | R6 | RC0603JR-07270RL | $0.10 | $0.10 | 1
2.7k Ohm | R7,R12 | RMCF0805JT2K70 | $0.10 | $0.20 | 2
100k Ohm | R6,R7,R10,R11, R12, R13, R14, R18 | RC0805FR-07100KL | $0.10 | $0.80 | 8
Totals: | $82.38 | 56

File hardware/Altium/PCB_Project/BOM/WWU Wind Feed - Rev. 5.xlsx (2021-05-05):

Quantity | Manufacturer | Manufacturer Part Number | Description | Package / Case | Designator | Supplier 1 | Supplier Unit Price 1
50 | [NoParam], [NoParam], [NoParam], [NoParam], [NoParam], [NoParam], [NoParam], [NoParam], [NoParam], [NoParam], [NoParam], [NoParam], [NoParam], [NoParam], [NoParam], [NoParam], [NoParam], [NoParam], [NoParam], [NoParam], [NoParam], [NoParam], [NoParam], [NoParam], [NoParam], [NoParam], [NoParam], [NoParam], [NoParam], [NoParam], [NoParam], [NoParam], [NoParam], [NoParam], [NoParam], [NoParam], [NoParam], [NoParam], [NoParam], [NoParam], [NoParam], [NoParam], [NoParam], [NoParam], [NoParam], National Semiconductor, [NoParam], [NoParam], Kyocera, [NoParam] |  | CAP 10uF 10V ±20% 0603 (1608 Metric) Thickness 1mm SMD, CAP 10uF 10V ±20% 0603 (1608 Metric) Thickness 1mm SMD, CAP 10uF 10V ±20% 0603 (1608 Metric) Thickness 1mm SMD, 0603 (1608 Metric) Chip Capacitor, CAP 10uF 10V ±20% 0603 (1608 Metric) Thickness 1mm SMD, CAP 10uF 10V ±20% 0603 (1608 Metric) Thickness 1mm SMD, CAP 10uF 10V ±20% 0603 (1608 Metric) Thickness 1mm SMD, CAP 10uF 10V ±20% 0603 (1608 Metric) Thickness 1mm SMD, CAP 10uF 10V ±20% 0603 (1608 Metric) Thickness 1mm SMD, CAP 10uF 10V ±20% 0603 (1608 Metric) Thickness 1mm SMD, CAP 10uF 10V ±20% 0603 (1608 Metric) Thickness 1mm SMD, CAP 10uF 10V ±20% 0603 (1608 Metric) Thickness 1mm SMD, CAP 10uF 10V ±20% 0603 (1608 Metric) Thickness 1mm SMD, CAP 10uF 10V ±20% 0603 (1608 Metric) Thickness 1mm SMD, CAP 10uF 10V ±20% 0603 (1608 Metric) Thickness 1mm SMD, [NoValue], [NoValue], [NoValue], 10 pin 0.05" pitch header for JTAG, [NoValue], Inductor, ESP8266 ESP-12-E, Header, 2-Pin, Dual row, Header, 5-Pin, Power Jack, 5 A, 250 V, 3-Pin SMD, RoHS, Bulk, Header, 2-Pin, Jumper 0603 (1608 Metric), Jumper 0603 (1608 Metric), 100K 0.125W 5% 0805 (2012 Metric) SMD, Jumper 0603 (1608 Metric), Jumper 0603 (1608 Metric), 100K 0.125W 5% 0805 (2012 Metric) SMD, 100K 0.125W 5% 0805 (2012 Metric) SMD, 100K 0.125W 5% 0805 (2012 Metric) SMD, Jumper 0603 (1608 Metric), 100K 0.125W 5% 0805 (2012 Metric) SMD, 100K 0.125W 5% 0805 (2012 Metric) SMD, 100K 0.125W 5% 0805 (2012 Metric) SMD, 100K 0.125W 5% 0805 (2012 Metric) SMD, 100K 0.125W 5% 0805 (2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 |  | C1, C2, C3, C4, C5, C6, C7, C8, C9, C10, C11, C12, C13, C14, C15, CN1, CN2, CN3, J1, J2, L1, M1, P1, P2, P3, P4, R1, R2, R3, R4, R5, R6, R7, R8, R9, R10, R11, R12, R13, R14, R15, R16, R17, R18, RF1, U1, U3, U4, X1, Y2
4 | TDK Corporation | MLZ2012N100LTD25 | Multilayer Inductor, 10 uH, ±20%, 300 mOhm, 50MHz, 0805(2012) | 0805 (2012 Metric) | L2, L3, L4, L5 | Digi-Key
1 | Keystone Electronics | 5001 | TEST POINT PC MINI .040"D BLACK |  | TP1 | Digi-Key
1 | Texas Instruments | CC3200R1M2RGC | SimpleLink Wi-Fi and Internet-of-Things Solution, a Single-Chip Wireless MCU, 2.1 to 3.6 V, -40 to 85 degC, 64-Pin PQFN (RGC64), Green (RoHS & no Sb/Br), Tray | 64-VFQFN Exposed Pad | U2 | Digi-Key
1 | Texas Instruments | TPS62172DSGR | Buck Step Down Regulator with 3 to 17 V Input and 3.3 V Output, -40 to 85 degC, 8-Pin WSON (DSG), Green (RoHS & no Sb/Br) | 8-WFDFN Exposed Pad | U5 | Digi-Key

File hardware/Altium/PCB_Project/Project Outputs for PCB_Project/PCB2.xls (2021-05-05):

 |  | Component list |  |  | Bill of Materials For PCB Document [PCB2.PcbDoc]
 |  | Source Data From: |  |  | PCB2.PcbDoc
 |  | Project: |  |  | PCB_Project.PrjPcb
 |  | Variant: |  |  | None
 |  | Report Date: |  | 3/17/2017 | 2:04:20 PM
 |  | Print Date: |  | 2017-03-17 | 14:04:23
Description | #Column Name Error:Footprint | Quantity | #Column Name Error:Units | Designator | #Column Name Error:Manufacturer1 | #Column Name Error:Manufacturer1 PN | #Column Name Error:Unit Price1 | #Column Name Error:Manufacturer2 | #Column Name Error:Manufacturer2 PN | #Column Name Error:Unit Price2 | Total Price ($)
Jumper 0603 (1608 Metric) |  | 3 |  | R5, R12, R13 |  |  |  |  |  |  | 0
 |  | 3 |  | CN1, CN2, CN3 |  |  |  |  |  |  | 0
2.4 GHz Filter |  | 1 |  | U4 |  |  |  |  |  |  | 0
100K 0.125W 5% 0805 (2012 Metric) SMD |  | 2 |  | R6, R11 |  |  |  |  |  |  | 0
0603 (1608 Metric) Chip Capacitor |  | 1 |  | C3 |  |  |  |  |  |  | 0
Crystal Unit, 8 pF, 25000 kHz, -10 to 70 degC, 4-Pin 3.2 x 2.5 x 0.8 mm SMD, RoHS, Tape and Reel |  | 1 |  | X1 |  |  |  |  |  |  | 0
100K 0.125W 5% 0805 (2012 Metric) SMD |  | 5 |  | R7, R8, R9, R10, R14 |  |  |  |  |  |  | 0
TEST POINT PC MINI .040"D BLACK |  | 5 |  | TP1, TP2, TP3, TP4, TP5 |  |  |  |  |  |  | 0
Buck Step Down Regulator with 3 to 17 V Input and 3.3 V Output, -40 to 85 degC, 8-Pin WSON (DSG), Green (RoHS & no Sb/Br) |  | 1 |  | U5 |  |  |  |  |  |  | 0
CAP 10uF 10V ±20% 0603 (1608 Metric) Thickness 1mm SMD |  | 8 |  | C1, C2, C4, C5, C6, C7, C8, C9 |  |  |  |  |  |  | 0
SimpleLink Wi-Fi and Internet-of-Things Solution, a Single-Chip Wireless MCU, 2.1 to 3.6 V, -40 to 85 degC, 64-Pin PQFN (RGC64), Green (RoHS & no Sb/Br), Tray |  | 1 |  | U2 |  |  |  |  |  |  | 0
Chip Antenna, 2.4 to 2.5 GHz, -40 to 85 degC, 2-Pin SMD, Pb-Free, Tape and Reel |  | 1 |  | RF1 |  |  |  |  |  |  | 0
Jumper 0603 (1608 Metric) |  | 4 |  | R1, R2, R3, R4 |  |  |  |  |  |  | 0
ESP8266 ESP-12-E |  | 1 |  | U3 |  |  |  |  |  |  | 0
10 pin 0.05" pitch header for JTAG |  | 1 |  | J1 |  |  |  |  |  |  | 0
Low Power Dual Operational Amplifier, 8-pin Narrow SOIC |  | 1 |  | U1 |  |  |  |  |  |  | 0
Multilayer Inductor, 10 uH, ±20%, 300 mOhm, 50MHz, 0805(2012) |  | 2 |  | L1, L2 |  |  |  |  |  |  | 0
Power Jack, 5 A, 250 V, 3-Pin SMD, RoHS, Bulk |  | 1 |  | P1 |  |  |  |  |  |  | 0
 |  | 1 |  | J2 |  |  |  |  |  |  | 0
 |  |  |  |  |  |  |  |  |  | TOTAL PRICE | 0.000

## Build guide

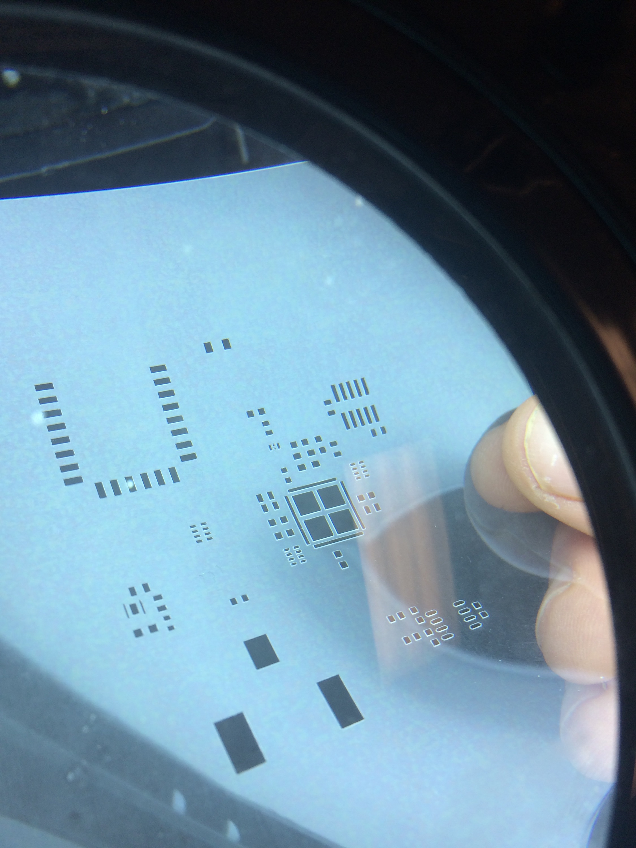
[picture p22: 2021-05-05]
images/1-Solder paste stencil.jpg

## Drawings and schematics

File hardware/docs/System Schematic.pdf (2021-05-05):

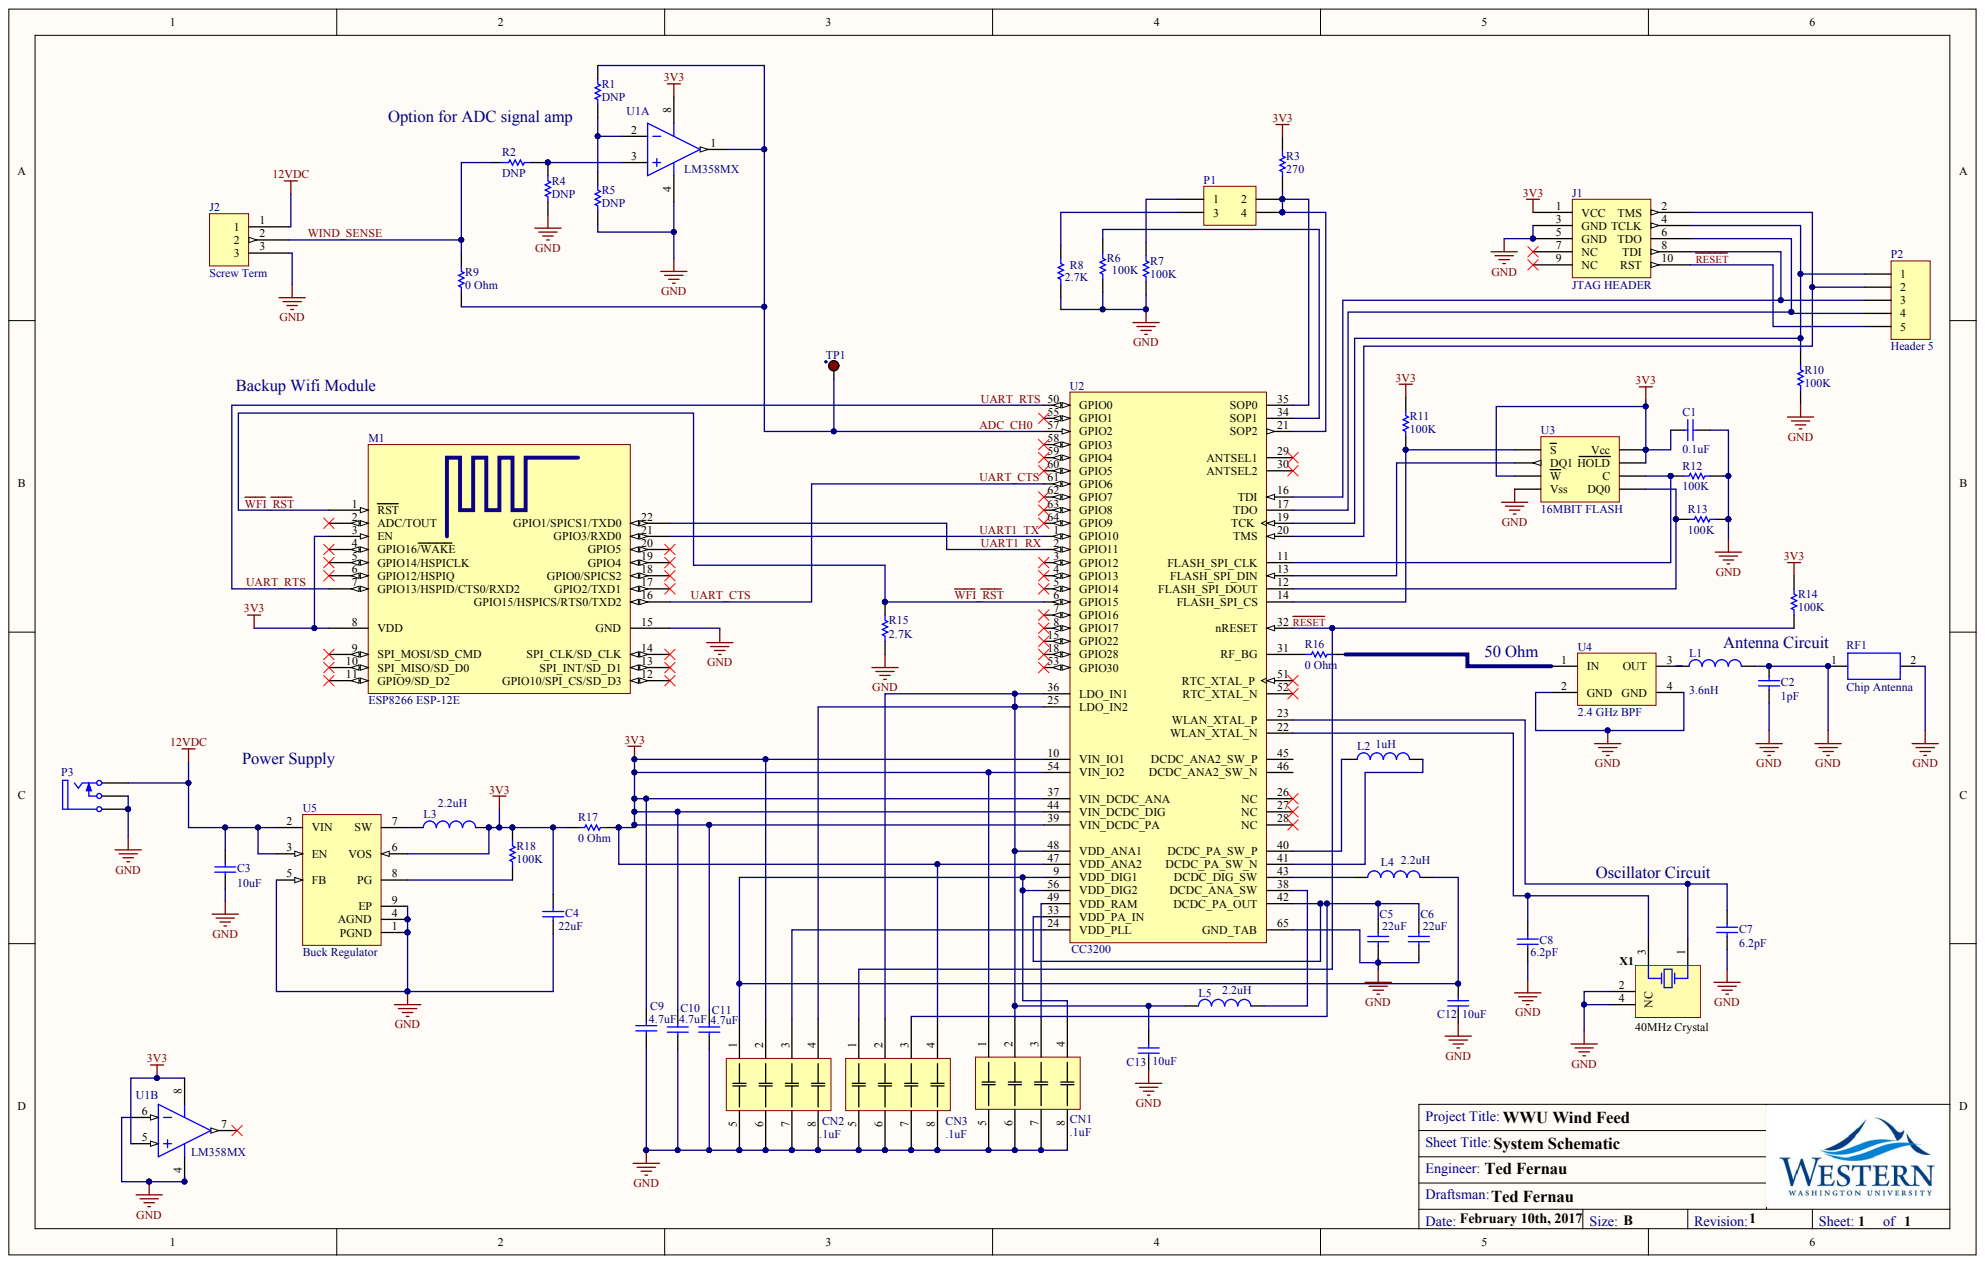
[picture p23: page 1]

Option for ADC signal amp

Backup Wifi Module Power Supply

6 0 | 3 0
6 1 | 1 6 | Vss DQ0C
6 2
6 3 | 1 7

4 | 17 GPIO0/SPICS2 18 GPIO4 19 GPIO5 20 GPIO3/RXD0 21 GPIO1/SPICS1/TXD0 22 6 GPIO2/TXD1 | UART1 _RX | 2 | 1 1 | 3V3 0

4 5 | 1 u H | Oscillator Circuit

1 0
5 4 | | 4 6 | | 2.2 u L4

3 7 | | 2 6
4 4 | | 2 7

WWU Win
Ted Fernau System Schematic
Ted Fernau

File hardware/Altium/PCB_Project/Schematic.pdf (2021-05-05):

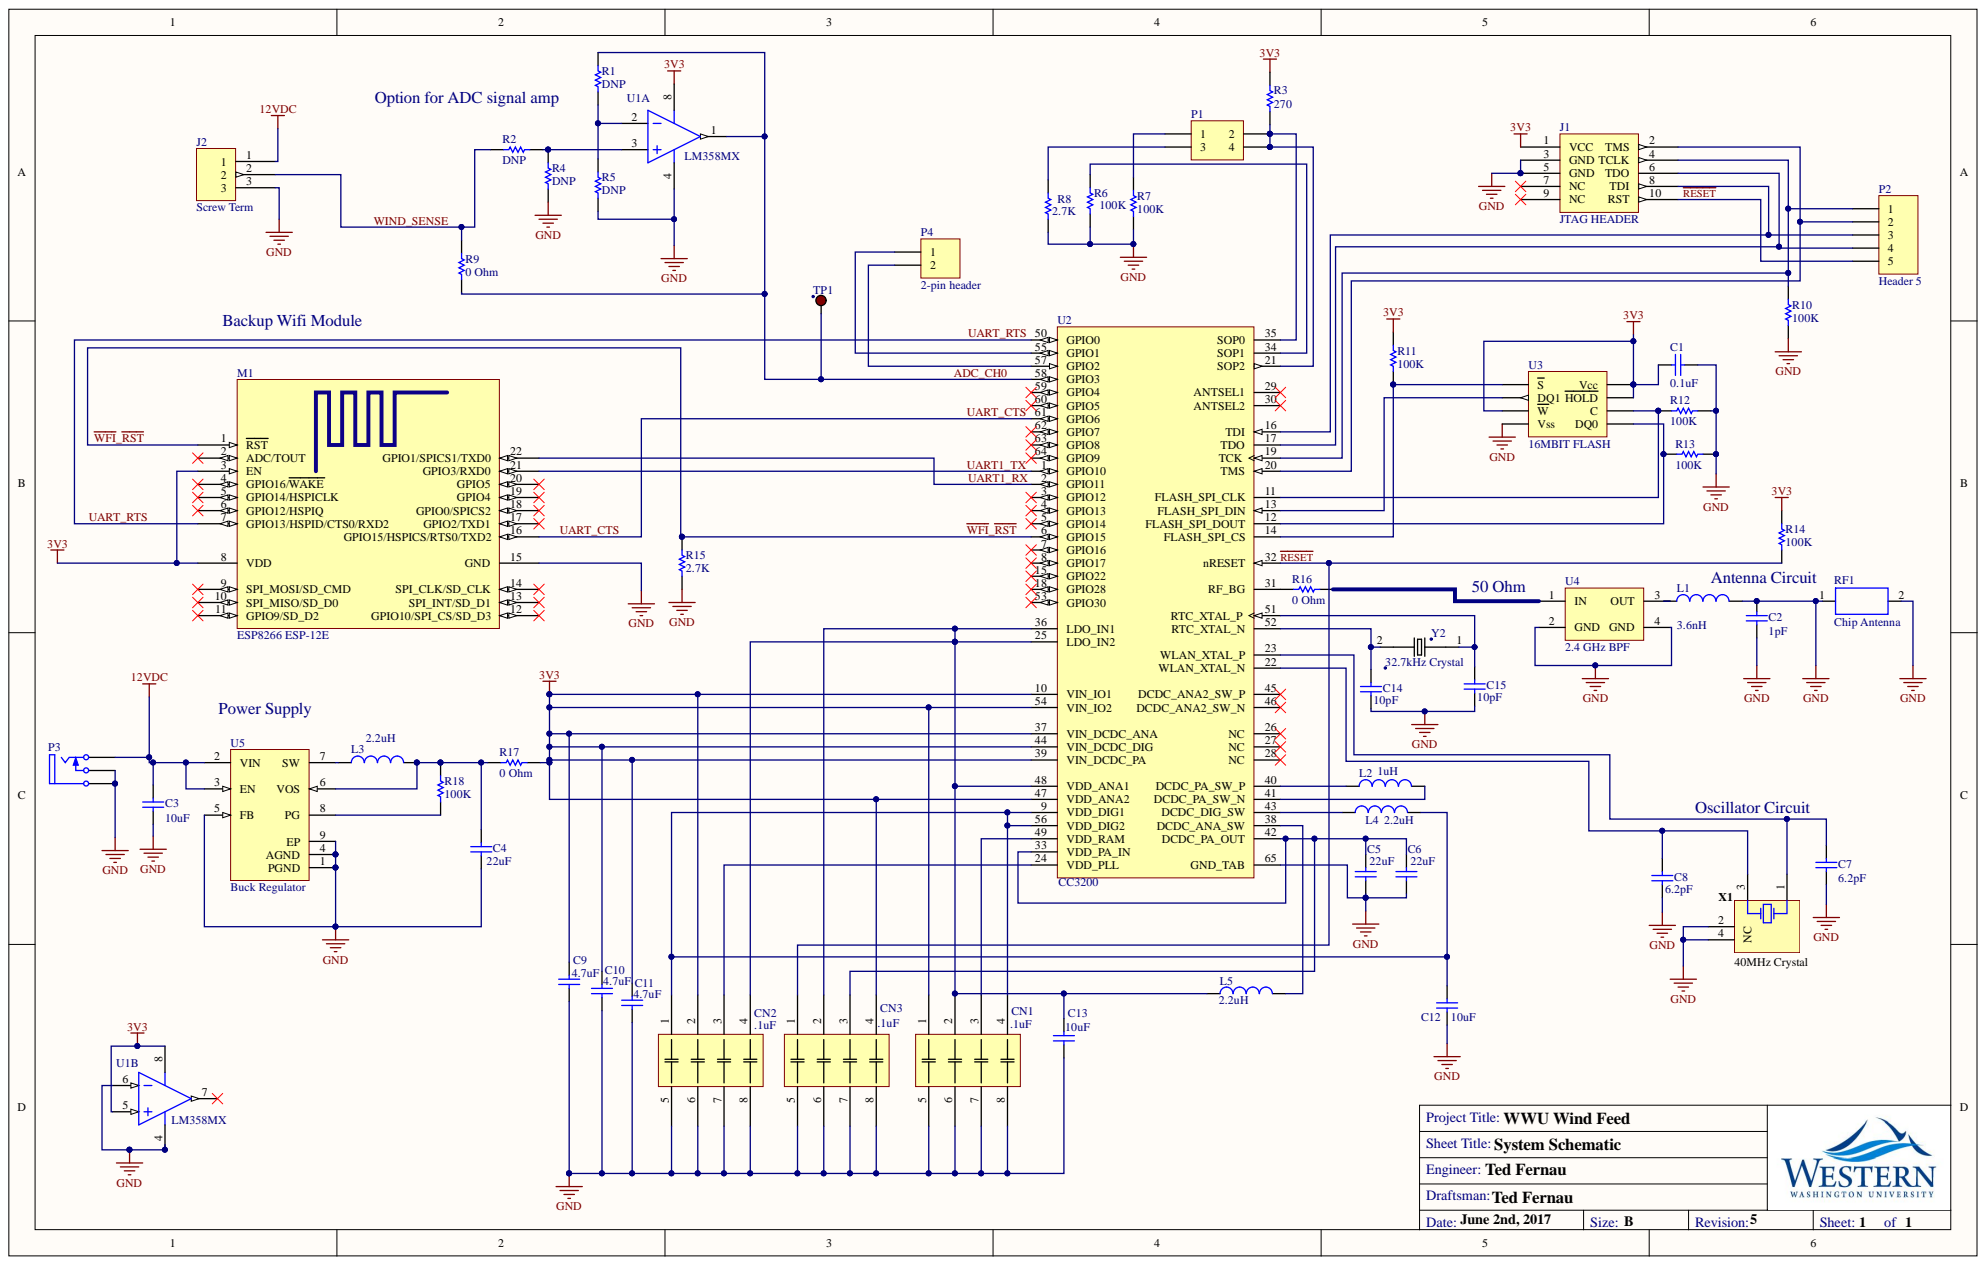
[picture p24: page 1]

Option for ADC signal amp

GPIO14/HSPICLK 5 | GPIO12 3

GPIO13/HSPID/CTS0/RXD2 7 | GPIO14 5

UART_CTS | WFI_RST | GPIO15 6

R15 | GPIO16 7

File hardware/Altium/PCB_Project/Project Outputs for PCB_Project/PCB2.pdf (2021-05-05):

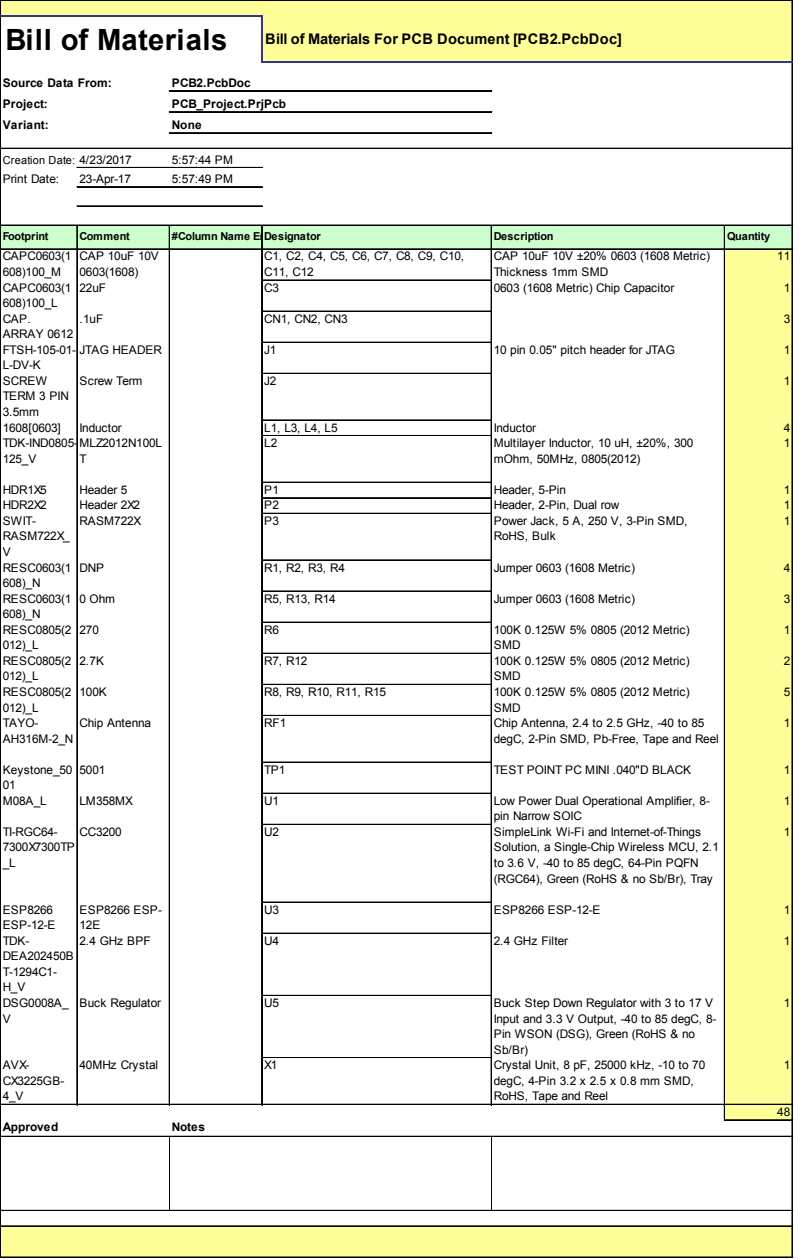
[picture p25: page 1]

Footprint | Comment | #Column Name ErDesignator | | Description | Quantity

degC, 2-Pin SMD, Pb-Free, Tape and Reel

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

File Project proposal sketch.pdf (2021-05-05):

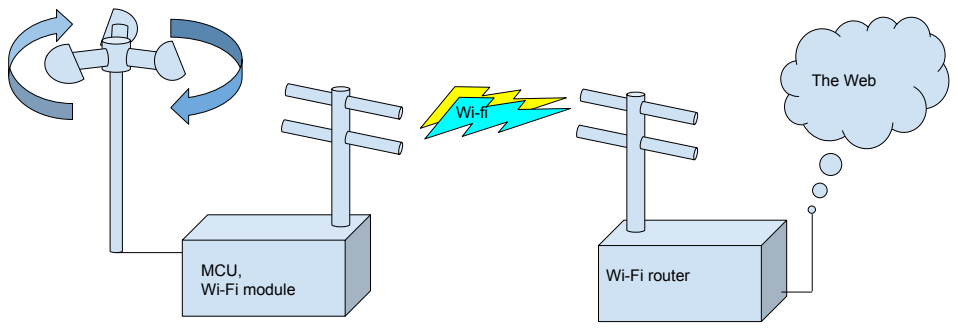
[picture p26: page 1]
The Web

MCU,
Wi-Fi module

Wi-Fi router

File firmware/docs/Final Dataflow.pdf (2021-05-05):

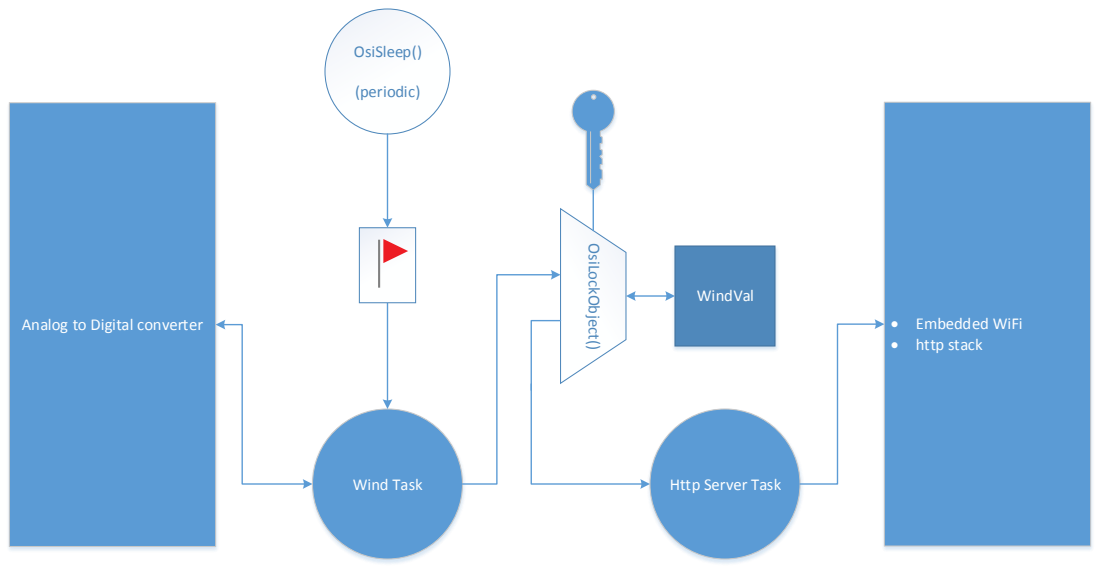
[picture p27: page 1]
Wind Task; OsiLockObject(); WindVal; • Embedded WiFi • http stack; OsiSleep(); (periodic)

Analog to Digital converter

Http Server Task

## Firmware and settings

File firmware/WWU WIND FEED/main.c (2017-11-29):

//*****************************************************************************
//
// Copyright (C) 2014 Texas Instruments Incorporated - http://www.ti.com/ 
// 
// 
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
//    Redistributions of source code must retain the above copyright 
//    notice, this list of conditions and the following disclaimer.
//
//    Redistributions in binary form must reproduce the above copyright
//    notice, this list of conditions and the following disclaimer in the 
//    documentation and/or other materials provided with the   
//    distribution.
//
//    Neither the name of Texas Instruments Incorporated nor the names of
//    its contributors may be used to endorse or promote products derived
//    from this software without specific prior written permission.
//
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
//*****************************************************************************

//*****************************************************************************
//
// Application Name     -   WWU Wind Feed, modified from HTTP Server example
// Application Overview -   This application reads the wind speed from an anemometer,
//                          and publishes the information on a local web page via Wifi

//modified by Ted Fernau, 5/2017
//
//*****************************************************************************


// Standard includes
#include <string.h>
#include <stdlib.h>
#include <stdint.h>
#include <stdbool.h>

// Simplelink includes
#include "simplelink.h"
#include "netcfg.h"

//driverlib includes
#include "hw_ints.h"
#include "hw_types.h"
#include "hw_memmap.h"
#include "hw_common_reg.h"
#include "hw_adc.h"
#include "hw_gprcm.h"
#include "interrupt.h"
#include "utils.h"
#include "pin.h"
#include "pinmux.h"
#include "uart.h"
#include "rom.h"
#include "rom_map.h"
#include "prcm.h"
#include "adc.h"

//Free_rtos/ti-rtos includes
#include "osi.h"

// common interface includes
#include "gpio_if.h"
#include "uart_if.h"
#include "common.h"

#include "smartconfig.h"
#include "pinmux.h"


#define APPLICATION_NAME        "WWU_WIND_FEED"
#define APPLICATION_VERSION     "1.1.1"
#define AP_SSID_LEN_MAX         (33)
#define ROLE_INVALID            (-5)

#define LED_STRING              "LED"
#define LED1_STRING             "LED1_"
#define LED2_STRING             ",LED2_"
#define LED_ON_STRING           "ON"
#define LED_OFF_STRING          "OFF"

#define SH_GPIO_3                       (3)  /* P58 - Device Mode */
#define ROLE_INVALID                    (-5)
#define AUTO_CONNECTION_TIMEOUT_COUNT   (50)   /* 5 Sec */


/*****************************************************
                    TEDs defines                              //todo 1  #defines
 *******************************************************/
#define OOB_TASK_PRIORITY               (1)       // higher number is higher priority
#define WIND_TASK_PRIORITY               (1)
#define OSI_STACK_SIZE                  (2048)
#define UART_PRINT         Report
#define FOREVER            1
#define NO_OF_SAMPLES       128
#define WIND_SPEED_FACTOR   39                     //conversion factor for wind speed estimate

/*****************************************************
                    END
 *******************************************************/




// Application specific status/error codes
typedef enum{
    // Choosing -0x7D0 to avoid overlap w/ host-driver's error codes
    LAN_CONNECTION_FAILED = -0x7D0,       
    INTERNET_CONNECTION_FAILED = LAN_CONNECTION_FAILED - 1,
    DEVICE_NOT_IN_STATION_MODE = INTERNET_CONNECTION_FAILED - 1,

    STATUS_CODE_MAX = -0xBB8
}e_AppStatusCodes;


//*****************************************************************************
//                 GLOBAL VARIABLES -- Start
//*****************************************************************************
volatile unsigned long  g_ulStatus = 0;//SimpleLink Status
unsigned long  g_ulPingPacketsRecv = 0; //Number of Ping Packets received 
unsigned long  g_ulGatewayIP = 0; //Network Gateway IP address
unsigned char  g_ucConnectionSSID[SSID_LEN_MAX+1]; //Connection SSID
unsigned char  g_ucConnectionBSSID[BSSID_LEN_MAX]; //Connection BSSID

static const char pcDigits[] = "0123456789";
unsigned char POST_token[] = "__SL_P_ULD";
unsigned char GET_token[]  = "__SL_G_ULD";
static unsigned char GET_token_TEMP[]  = "__SL_G_UTP";              //this is the handle for the token which is polled by javascript
int g_iSimplelinkRole = ROLE_INVALID;
signed int g_uiIpAddress = 0;
unsigned char g_ucSSID[AP_SSID_LEN_MAX];




/*****************************************************
                                                  //todo 2 Global variables
 *******************************************************/
unsigned long Adc_Samples [4096];
unsigned long Adc_Sample;
float Cur_Voltage;
float Voltages [NO_OF_SAMPLES];
float Wind_Speed;                                     //  This is the calculated wind speed

struct Wind_Struct {                                //This structure holds the shared wind data object and the lock parameter
    double fCurrentTemp;
   OsiLockObj_t LockObj;
} Wind_Object;                                       //there is only 1 instance

/*****************************************************
                    END
 *******************************************************/


#if defined(ccs)
extern void (* const g_pfnVectors[])(void);
#endif
#if defined(ewarm)
extern uVectorEntry __vector_table;
#endif
//*****************************************************************************
//                 GLOBAL VARIABLES -- End
//*****************************************************************************



//****************************************************************************
//                      LOCAL FUNCTION PROTOTYPES
//****************************************************************************
static long WlanConnect();

//*****************************************************************************
// Variable related to Connection status
//*****************************************************************************
volatile unsigned short g_usMCNetworkUstate = 0;

int g_uiSimplelinkRole = ROLE_INVALID;
unsigned int g_uiDeviceModeConfig = ROLE_STA; //default is STA mode
volatile unsigned char g_ucConnectTimeout =0;



#ifdef USE_FREERTOS         //looks like we are using Free RTOS
//*****************************************************************************
// FreeRTOS User Hook Functions enabled in FreeRTOSConfig.h
//*****************************************************************************

//*****************************************************************************
//
//! \brief Application defined hook (or callback) function - assert
//!
//! \param[in]  pcFile - Pointer to the File Name
//! \param[in]  ulLine - Line Number
//!
//! \return none
//!
//*****************************************************************************
void
vAssertCalled( const char *pcFile, unsigned long ulLine )
{
    //Handle Assert here
    while(1)
    {
    }
}

//*****************************************************************************
//
//! \brief Application defined idle task hook
//!
//! \param  none
//!
//! \return none
//!
//*****************************************************************************
void
vApplicationIdleHook( void)
{
    //Handle Idle Hook for Profiling, Power Management etc
}

//*****************************************************************************
//
//! \brief Application defined malloc failed hook
//!
//! \param  none
//!
//! \return none
//!
//*****************************************************************************
void vApplicationMallocFailedHook()
{
    //Handle Memory Allocation Errors
    while(1)
    {
    }
}

//*****************************************************************************
//
//! \brief Application defined stack overflow hook
//!
//! \param  none
//!
//! \return none
//!
//*****************************************************************************
void vApplicationStackOverflowHook( OsiTaskHandle *pxTask,
                                   signed char *pcTaskName)
{
        ( void ) pxTask;
        ( void ) pcTaskName;

    //Handle FreeRTOS Stack Overflow
    while(1)
    {
    }
}
#endif //USE_FREERTOS


//*****************************************************************************
//
//! itoa
//!
//!    @brief  Convert integer to ASCII in decimal base
//!
//!     @param  cNum is input integer number to convert
//!     @param  cString is output string
//!
//!     @return number of ASCII parameters
//!
//!
//
//*****************************************************************************
static unsigned short itoa(char cNum, char *cString)
{
    char* ptr;
    char uTemp = cNum;
    unsigned short length;

    // value 0 is a special case
    if (cNum == 0)
    {
        length = 1;
        *cString = '0';

        return length;
    }

    // Find out the length of the number, in decimal base
    length = 0;
    while (uTemp > 0)
    {
        uTemp /= 10;
        length++;
    }

    // Do the actual formatting, right to left
    uTemp = cNum;
    ptr = cString + length;
    while (uTemp > 0)
    {
        --ptr;
        *ptr = pcDigits[uTemp % 10];
        uTemp /= 10;
    }

    return length;
}



//*****************************************************************************
// SimpleLink Asynchronous Event Handlers -- Start
//*****************************************************************************


//*****************************************************************************
//
//! \brief The Function Handles WLAN Events
//!
//! \param[in]  pWlanEvent - Pointer to WLAN Event Info
//!
//! \return None
//!
//*****************************************************************************
void SimpleLinkWlanEventHandler(SlWlanEvent_t *pWlanEvent)
{
    if(!pWlanEvent)
    {
        return;
    }

    switch(pWlanEvent->Event)
    {
        case SL_WLAN_CONNECT_EVENT:
        {
            SET_STATUS_BIT(g_ulStatus, STATUS_BIT_CONNECTION);
            
            //
            // Information about the connected AP (like name, MAC etc) will be
            // available in 'slWlanConnectAsyncResponse_t'-Applications
            // can use it if required
            //
            //  slWlanConnectAsyncResponse_t *pEventData = NULL;
            // pEventData = &pWlanEvent->EventData.STAandP2PModeWlanConnected;
            //
            
            // Copy new connection SSID and BSSID to global parameters
            memcpy(g_ucConnectionSSID,pWlanEvent->EventData.
                   STAandP2PModeWlanConnected.ssid_name,
                   pWlanEvent->EventData.STAandP2PModeWlanConnected.ssid_len);
            memcpy(g_ucConnectionBSSID,
                   pWlanEvent->EventData.STAandP2PModeWlanConnected.bssid,
                   SL_BSSID_LENGTH);

            UART_PRINT("[WLAN EVENT] STA Connected to the AP: %s ,"
                        "BSSID: %x:%x:%x:%x:%x:%x\n\r",
                      g_ucConnectionSSID,g_ucConnectionBSSID[0],
                      g_ucConnectionBSSID[1],g_ucConnectionBSSID[2],
                      g_ucConnectionBSSID[3],g_ucConnectionBSSID[4],
                      g_ucConnectionBSSID[5]);
        }
        break;

        case SL_WLAN_DISCONNECT_EVENT:
        {
            slWlanConnectAsyncResponse_t*  pEventData = NULL;

            CLR_STATUS_BIT(g_ulStatus, STATUS_BIT_CONNECTION);
            CLR_STATUS_BIT(g_ulStatus, STATUS_BIT_IP_AQUIRED);

            pEventData = &pWlanEvent->EventData.STAandP2PModeDisconnected;

            // If the user has initiated 'Disconnect' request, 
            //'reason_code' is SL_WLAN_DISCONNECT_USER_INITIATED_DISCONNECTION 
            if(SL_WLAN_DISCONNECT_USER_INITIATED_DISCONNECTION == pEventData->reason_code)
            {
                UART_PRINT("[WLAN EVENT]Device disconnected from the AP: %s,"
                "BSSID: %x:%x:%x:%x:%x:%x on application's request \n\r",
                           g_ucConnectionSSID,g_ucConnectionBSSID[0],
                           g_ucConnectionBSSID[1],g_ucConnectionBSSID[2],
                           g_ucConnectionBSSID[3],g_ucConnectionBSSID[4],
                           g_ucConnectionBSSID[5]);
            }
            else
            {
                UART_PRINT("[WLAN ERROR]Device disconnected from the AP AP: %s,"
                "BSSID: %x:%x:%x:%x:%x:%x on an ERROR..!! \n\r",
                           g_ucConnectionSSID,g_ucConnectionBSSID[0],
                           g_ucConnectionBSSID[1],g_ucConnectionBSSID[2],
                           g_ucConnectionBSSID[3],g_ucConnectionBSSID[4],
                           g_ucConnectionBSSID[5]);
            }
            memset(g_ucConnectionSSID,0,sizeof(g_ucConnectionSSID));
            memset(g_ucConnectionBSSID,0,sizeof(g_ucConnectionBSSID));
        }
        break;

        case SL_WLAN_STA_CONNECTED_EVENT:
        {
            // when device is in AP mode and any client connects to device cc3xxx
            SET_STATUS_BIT(g_ulStatus, STATUS_BIT_CONNECTION);
            CLR_STATUS_BIT(g_ulStatus, STATUS_BIT_CONNECTION_FAILED);

            //
            // Information about the connected client (like SSID, MAC etc) will
            // be available in 'slPeerInfoAsyncResponse_t' - Applications
            // can use it if required
            //
            // slPeerInfoAsyncResponse_t *pEventData = NULL;
            // pEventData = &pSlWlanEvent->EventData.APModeStaConnected;
            //

        }
        break;

        case SL_WLAN_STA_DISCONNECTED_EVENT:
        {
            // when client disconnects from device (AP)
            CLR_STATUS_BIT(g_ulStatus, STATUS_BIT_CONNECTION);
            CLR_STATUS_BIT(g_ulStatus, STATUS_BIT_IP_LEASED);

            //
            // Information about the connected client (like SSID, MAC etc) will
            // be available in 'slPeerInfoAsyncResponse_t' - Applications
            // can use it if required
            //
            // slPeerInfoAsyncResponse_t *pEventData = NULL;
            // pEventData = &pSlWlanEvent->EventData.APModestaDisconnected;
            //
        }
        break;

        case SL_WLAN_SMART_CONFIG_COMPLETE_EVENT:
        {
            SET_STATUS_BIT(g_ulStatus, STATUS_BIT_SMARTCONFIG_START);

            //
            // Information about the SmartConfig details (like Status, SSID,
            // Token etc) will be available in 'slSmartConfigStartAsyncResponse_t'
            // - Applications can use it if required
            //
            //  slSmartConfigStartAsyncResponse_t *pEventData = NULL;
            //  pEventData = &pSlWlanEvent->EventData.smartConfigStartResponse;
            //

        }
        break;

        case SL_WLAN_SMART_CONFIG_STOP_EVENT:
        {
            // SmartConfig operation finished
            CLR_STATUS_BIT(g_ulStatus, STATUS_BIT_SMARTCONFIG_START);

            //
            // Information about the SmartConfig details (like Status, padding
            // etc) will be available in 'slSmartConfigStopAsyncResponse_t' -
            // Applications can use it if required
            //
            // slSmartConfigStopAsyncResponse_t *pEventData = NULL;
            // pEventData = &pSlWlanEvent->EventData.smartConfigStopResponse;
            //
        }
        break;

        case SL_WLAN_P2P_DEV_FOUND_EVENT:
        {
            SET_STATUS_BIT(g_ulStatus, STATUS_BIT_P2P_DEV_FOUND);

            //
            // Information about P2P config details (like Peer device name, own
            // SSID etc) will be available in 'slPeerInfoAsyncResponse_t' -
            // Applications can use it if required
            //
            // slPeerInfoAsyncResponse_t *pEventData = NULL;
            // pEventData = &pSlWlanEvent->EventData.P2PModeDevFound;
            //
        }
        break;

        case SL_WLAN_P2P_NEG_REQ_RECEIVED_EVENT:
        {
            SET_STATUS_BIT(g_ulStatus, STATUS_BIT_P2P_REQ_RECEIVED);

            //
            // Information about P2P Negotiation req details (like Peer device
            // name, own SSID etc) will be available in 'slPeerInfoAsyncResponse_t'
            //  - Applications can use it if required
            //
            // slPeerInfoAsyncResponse_t *pEventData = NULL;
            // pEventData = &pSlWlanEvent->EventData.P2PModeNegReqReceived;
            //
        }
        break;

        case SL_WLAN_CONNECTION_FAILED_EVENT:
        {
            // If device gets any connection failed event
            SET_STATUS_BIT(g_ulStatus, STATUS_BIT_CONNECTION_FAILED);
        }
        break;

        default:
        {
            UART_PRINT("[WLAN EVENT] Unexpected event [0x%x]\n\r",
                       pWlanEvent->Event);
        }
        break;
    }
}

//*****************************************************************************
//
//! \brief This function handles network events such as IP acquisition, IP
//!           leased, IP released etc.
//!
//! \param[in]  pNetAppEvent - Pointer to NetApp Event Info 
//!
//! \return None
//!
//*****************************************************************************
void SimpleLinkNetAppEventHandler(SlNetAppEvent_t *pNetAppEvent)
{
    if(!pNetAppEvent)
    {
        return;
    }

    switch(pNetAppEvent->Event)
    {
        case SL_NETAPP_IPV4_IPACQUIRED_EVENT:
        {
            SlIpV4AcquiredAsync_t *pEventData = NULL;

            SET_STATUS_BIT(g_ulStatus, STATUS_BIT_IP_AQUIRED);
            
            //Ip Acquired Event Data
            pEventData = &pNetAppEvent->EventData.ipAcquiredV4;
            g_uiIpAddress = pEventData->ip;

            //Gateway IP address
            g_ulGatewayIP = pEventData->gateway;
            
            /*UART_PRINT("[NETAPP EVENT] IP Acquired: IP=%d.%d.%d.%d , "
            "Gateway=%d.%d.%d.%d\n\r", 
            SL_IPV4_BYTE(pNetAppEvent->EventData.ipAcquiredV4.ip,3),
            SL_IPV4_BYTE(pNetAppEvent->EventData.ipAcquiredV4.ip,2),
            SL_IPV4_BYTE(pNetAppEvent->EventData.ipAcquiredV4.ip,1),
            SL_IPV4_BYTE(pNetAppEvent->EventData.ipAcquiredV4.ip,0),
            SL_IPV4_BYTE(pNetAppEvent->EventData.ipAcquiredV4.gateway,3),
            SL_IPV4_BYTE(pNetAppEvent->EventData.ipAcquiredV4.gateway,2),
            SL_IPV4_BYTE(pNetAppEvent->EventData.ipAcquiredV4.gateway,1),
            SL_IPV4_BYTE(pNetAppEvent->EventData.ipAcquiredV4.gateway,0));
            */
        }
        break;

        case SL_NETAPP_IP_LEASED_EVENT:
        {
            SET_STATUS_BIT(g_ulStatus, STATUS_BIT_IP_LEASED);

            //
            // Information about the IP-Leased details(like IP-Leased,lease-time,
            // mac etc) will be available in 'SlIpLeasedAsync_t' - Applications
            // can use it if required
            //
            // SlIpLeasedAsync_t *pEventData = NULL;
            // pEventData = &pNetAppEvent->EventData.ipLeased;
            //

        }
        break;

        case SL_NETAPP_IP_RELEASED_EVENT:
        {
            CLR_STATUS_BIT(g_ulStatus, STATUS_BIT_IP_LEASED);

            //
            // Information about the IP-Released details (like IP-address, mac
            // etc) will be available in 'SlIpReleasedAsync_t' - Applications
            // can use it if required
            //
            // SlIpReleasedAsync_t *pEventData = NULL;
            // pEventData = &pNetAppEvent->EventData.ipReleased;
            //
        }
		break;

        default:
        {
            UART_PRINT("[NETAPP EVENT] Unexpected event [0x%x] \n\r",
                       pNetAppEvent->Event);
        }
        break;
    }
}
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
void main()
{
    long lRetVal = -1;

 /*                         initialize
 ****************************************************************************/

    BoardInit();        //Board Initialization
    PinMuxConfig();     //Pin Configuration
    MAP_PinConfigSet(PIN_58,PIN_STRENGTH_2MA|PIN_STRENGTH_4MA,PIN_TYPE_STD_PD);     //Change Pin 58 Configuration from Default to Pull Down

    GPIO_IF_LedConfigure(LED1|LED2|LED3);            // Initialize GREEN and ORANGE LED
    GPIO_IF_LedOff(MCU_ALL_LED_IND);                 //Turn Off the LEDs

    MAP_PRCMPeripheralReset(PRCM_UARTA0);            //UART Initialization
    InitTerm();


    /*                         run
     ****************************************************************************/

    DisplayBanner(APPLICATION_NAME);                 //Display Application Banner on UART Terminal


    lRetVal = VStartSimpleLinkSpawnTask(SPAWN_TASK_PRIORITY);           // Simplelinkspawntask
    if(lRetVal < 0)
    {
        UART_PRINT("Unable to start simplelink spawn task\n\r");
        LOOP_FOREVER();
    }


    lRetVal = osi_TaskCreate(HTTPServerTask, (signed char*)"HTTPServerTask",            // Create HTTP Server Task
                         OSI_STACK_SIZE, NULL, OOB_TASK_PRIORITY, NULL );
    if(lRetVal < 0)
    {
        UART_PRINT("Unable to create  HTTPServerTask \n\r");
        LOOP_FOREVER();
    }


    lRetVal = osi_TaskCreate(WindTask, (signed char*)"WindTask",                        // Create WIND Task
                         OSI_STACK_SIZE, NULL, WIND_TASK_PRIORITY, NULL );
    if(lRetVal < 0)
    {
        UART_PRINT("Unable to create  WindTask \n\r");
        LOOP_FOREVER();
    }


    lRetVal =  osi_LockObjCreate(&Wind_Object.LockObj);                     //Create Mutex for Wind data object
    if(lRetVal < 0)
    {
        UART_PRINT("Unable to create  mutex key");
        LOOP_FOREVER();
    }


    osi_start();                                                                 // Start OS Scheduler

    while (1)
    {

    }

}

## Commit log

2017-05-04 This is my initial commit.
    These projects represent the resources I may use for my project.
    When I am sure of my final design, I will cut all extra resources.
    these projects require the CC3200 SDK as well as some CCS
    plugins/updates to build. I can accumulate more resources into the repo
    as needed
    [app_pem4.cfg, app_pem4.cfg.xml, app_pem4.rta.xml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]
2017-05-04 commit after build.
    I am unfamiliar with some of the files produced by CCS after building
    [cc_pal.obj, device.obj, driver.obj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]
2017-05-04 Removed post-compilation variables
    [app_pem4.cfg, app_pem4.cfg.xml, app_pem4.rta.xml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]
2017-05-05 This is an attempt to integrate ADC code into the http server example.
    the http server project builds and runs, but produces a garbage voltage.
    The next step is to refine the ADC to produce an accurate wind speed
    based on my instrument.
    the http server example requires configuration via smartphone; another
    next step is to configure the device at build-time and modify the web
    page.
2017-05-24 configured pin-muxing for my PCB instead of Launchpad Dev Board
    [summary.csv]
2017-05-25 Move ADC to Wind Task
2017-05-31 This is a big commit
    I got my dev board to serve my web page and implemented a periodic wind
    speed task
    Unfortunately I forgot to commit while things were good, and I am now
    experiencing new bugs. I shold be able to track them down or else revert
    my previous commit and start again.
    This is not where I wanted my code to be for code reviews, but I am
    close to having the thing running, and could thus use some critical
    feedback.
    I have been putting priority on getting something working for demo day,
    and have not been focusing on conventions/best practices.
    I am hoping to clean my code up for thursdays review, but this version
    would work for a review.
    [main.c]
2017-06-03 Almost updating the wind speed
    The program now serves a question mark error code in the wind speed
    area.
    This is a step towards posting wind speeds.
    [main.c]
2017-06-04 Getting closer
    This program reads the ADC, takes an average, calculates a somewhat
    accurate wind speed. and passes the value as an INTEGER to the web page.
    The value is not refreshing at all. the value is passed once and does
    not update automatically (as it should) or upon page refresh. This means
    I am not actually polling the token, just reading it once. This could be
    because my OS hits a snag, the JS functions are not seu up correctly, or
    I am not updating the token how I think I am.
    To do:
    eliminate the need for smartphone configuration upon reset
    implement dynamic/static wind speed updating
    implement requirement of .1 knot resolution, instead of 1kt
    [main.c]
2017-06-04 this project works
    I am having trouble with the program in debug mode, but when I flash the
    image into the board the program works.
    *it updates the wind speed approximately every second, without
    refreshing the page.
    * it connects automatically to the Wifi router, the info for which is in
    common.h
    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
2017-06-04 I attempted to change the domain name of the webpage, but failed
    I may just leave the default setting.
    todo:
    implement tenth-of-a-knot precision
    [main.c]
2021-05-04 Added more project documents
    [12V_Barrel Jack.PcbLib, PCB1.PcbDoc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]
